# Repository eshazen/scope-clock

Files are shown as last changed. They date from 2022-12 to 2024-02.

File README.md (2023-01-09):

# Oscilloscope Clock

OK, time to jump on the oscilloscope clock bandwagon!
It's an old idea, but they just look so cool.

* [Wiki Page](http://hertz.bu.edu/~hazen/wiki/en/#!mdwiki/ScopeClock.md)

This was going to be a simple clone of some rather simplistic
transistor-based designs around the internet, but now I've got
something more ambitious in mind!  Here's the prototype in action:

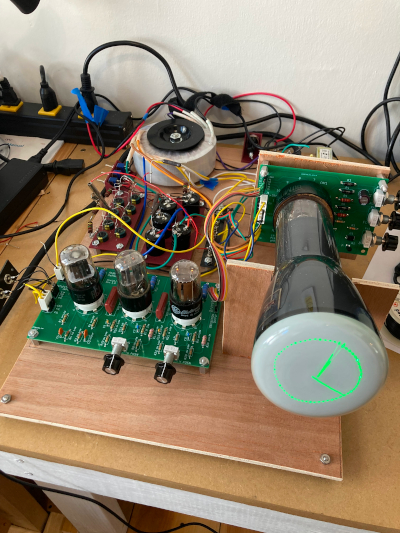
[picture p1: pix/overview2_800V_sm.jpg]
Prototype

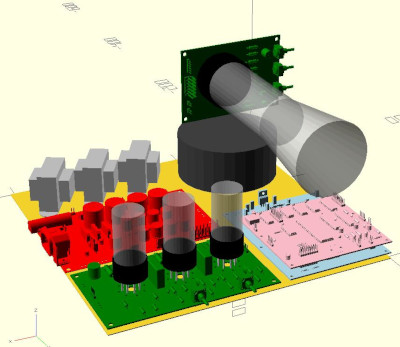
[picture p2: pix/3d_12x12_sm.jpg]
3D View


## Hardware

* 3BP1(A) CRT with proper drive to +360/-1400V [pcb](https://github.com/eshazen/scope-clock/tree/main/hardware/anderson_crt)
* Tube-based deflection circuit using 6SN7 or 12SN7 dual triodes [pcb](https://github.com/eshazen/scope-clock/tree/main/hardware/deflection_amp)
* Voltage-multiplier HV supply using an Antek transformer
* Display-list based vector graphics generator (or could cheat and use a uC)

## Attribution

The CRT circuit is directly inspired by Steve Anderson's narrow-bandwidth TV (NBTV) monitor design, as found at https://www.taswegian.com/NBTV/forum/index.php.

**Status**

**2021-01-14** - Rev A tag after DAC PCBs and parts ordered.

Now looking at the power supply.

**2022-12-28** - more or less working.  Hand-wired high voltage
supply.  CRT PCB and deflection amp working with only a couple of tiny
issues.

Open issues:

* Deflection amp gets quite non-linear at around 60% deflection (-1600V on CRT).  At -800V it's fine.  Low end of diff output leg is around 250V.  The range 250-320 works well.
* If you switch off all the supplies together the CRT arcs inside (oops!).  Need to shut down the -1500V first and wait many seconds, then turn off the others.  Really need to figure out some sort of shutdown circuit
* The input has to be driven by a laptop.

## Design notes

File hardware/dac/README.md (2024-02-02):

# DAC board

This is the control/interface board, designed to work with the Z80 CPU board from my retro-25 calculator project [git](https://github.com/eshazen/retro-25/tree/master/hardware/cpu/RevA).

**See bottom for ECOs**

Features:

* MAX503/530 DAC.  Needs 1 address bit and 8 bit data with strobe.
* UART with FT232 USB interface.  Thinking of IM6402 since it's dead simple.  Needs a 16X clock.
* Buttons, encoders, maybe a couple of LED drives
* Z-axis drive (9-12V to J2 on CRT board; could be +/-5V)
* Real-time clock e.g. DS1306

The CPU board interface is somewhat limited-- there are only two decoded nIORQ+Addr strobes and no access to nWR or nRD.  However, there is one address line and 5 latched outputs, which could be used for direction or additional address decoding.

## J1 (16 pins)

This connector was intended to drive an LED board.  It has the
unbuffered data buss, one address line and two strobes decoded with
nIORQ and address only.

| Notes | Pin | | Pin | Notes |
|---|-----|---|-----|---|
| +5V | 1 | | 2 | D0 (unbuffered) |
| +5V | 3 | | 4 | D1 |
| GND | 5 | | 6 | D2 |
| GND | 7 | | 8 | D3 |
| GND | 9 | | 10  | D4 |
| nLED2 (strobe)  | 11  | | 12  | D5 |
| nLED1 (strobe)  | 13  | | 14  | D6 |
| A0 (unbuffered) | 15  | | 16  | D7 |

## J3 (16 pins)

This connector was intended to scan a matrix keyboard.  It has 5
latched outputs and 7 buffered inputs with pull-ups to +5.  There is
no access to the read strobe, so data to be read should be latched
somehow.  Also, there is no GND on this connector.

| Notes | Pin | | Pin | Notes |
|---|-----|---|-----|---|
| N/A | 1 | | 2 | N/A |
| N/A | 3 | | 4 | Input D0 |
| Input  D4 | 5 | | 6 | Input D1 |
| Output Q4 | 7 | | 8 | Input D2 |
| Output Q3 | 9 | | 10  | Input D3 |
| Output Q2 | 11  | | 12  | Input D4 |
| Output Q1 | 13  | | 14  | Input D5 |
| Output Q0 | 15  | | 16  | Input D6 |

## I/O Mapping/Decoding

**CPU I/O decode**

    00 - KB/serial WR
	40 - nLED1 WR       (functions via U5)
	80 - KB/serial RD
	C0 - nLED2 WR       (access RTC when Q4 high)
	
Strobe nLED1 (address 0x40) accesses the DAC.  This is write-only (Q0
must be '1') with the channel selected by Q1.  Address A0 selects the
low 8 bits or upper 4 bits of the DAC data.  Strobe nLED2 accesses
either the UART or the switch/LED register selected by Q2.

### Output bits (address 0)

| Bit | Function | 0 | 1 |
|-----|---|---|---|
| Q0  | Bus direction | RD | WR |
| | LSB of U5 | even addr | odd addr |
| Q1  | A2 of U5 | | |
| Q2  | Z enable | Z enabled | Z disabled |
| Q3  | UART reset | | reset UART |
| Q4  | RTC CE | | enable RTC access |
| | | | |

### Input bits (address 80)

| Bit | Value | Function |
|-----|---|---|
| KD0 | 01 | Shaft encoder sw |
| KD1 | 02 | Shaft encoder A  |
| KD2 | 04 | Shaft encoder B  |
| KD3 | 08 | SW1 |
| KD4 | 10 | SW2 |
| KD5 | 20 | RTC SDO |
| KD6 | | |

### LS138 (U5)

Accessed at addresses 40/41

| Zero | Addr | Q1 | A0 | Q0 | Function |
|---|---|----|----|----|---|
| 0 | 40 | 0  | 0  | 0  | UART Data Rd |
| 1 | 40 | 0  | 0  | 1  | UART Data Wr |
| 0 | 41 | 0  | 1  | 0  | Uart Status Rd |
| 1 | 41 | 0  | 1  | 1  | `nEXP` expansion latch Wr |
| 2 | 40 | 1  | 0  | 0  | |
| 3 | 40 | 1  | 0  | 1  | `nDACY` H=idle, L=load DACs, reset DAC addr |
| 2 | 41 | 1  | 1  | 0  | |
| 3 | 41 | 1  | 1  | 1  | `nDACX` L->H write DAC data, increment DAC addr |

### U3 expansion

Access by writing to address 41 with port zero low bits set to '01'.

| Bit | Funct |
|-----|---|
| 0 | LED D1 |
| 1 | LED D2 |
| 2 | LED D3 |
| 3 | RTC SDI |
| 4 | HV Enable |
| 5 | |

Propse to buffer the data with a latched output used to set direction,
and enable on the 'or' of the two decoded strobes.  Additional latched
outputs would serve as a device select.

The DAC (MAX503 or MAX530) requires only a strobe (nWR) and one
address line (A0, A1 tied) to update 10 or 12 bits using two successive write operations.

Each DAC would be mapped to two addresses so once enabled it could be
written fast using two I/O writes per word.  A single additional write
would be required to switch between X and Y channels using a device
select bit.

The UART requires one status port, one latched control port and input and output data ports.

## Changed for Rev 2

* Transistor pinout (Q1) is wrong **fixed**
* Jumper pins 22, 23 of U8, U9 (+5V to DAC missing) **fixed**

### Modifications to make the DAC run faster

* Add a '161 and a '139 so that the address cycles through the 4 DAC bytes automatically:
   * Disconnect nCE and wire to nWR **fixed**
   * Disconnect nLDAC and wire to nDACY (also to '161 nRESET)
   * Disconnect nDACX and wire to '161 CP and '139 nEN **fixed**
   * Wire '161 Q1 to '139 A0. **fixed**
   * Ground '139 A1 **fixed** 
   * Wire 139 O0 to DAC_X nWR and nCE **fixed**
   * Wire 139 O1 to DAC_Y nWR and nCE **fixed**
   * Wire '161 Q0 to both DAC A0+A1  **fixed**
* cut trace to pins 8,9 of U8, U9 (DAC A0, A1) **fixed**
* (wire U8 pin 8 to U3 pin 10) nope.  That's A0/A1 taken care of above
* Ground 12, 14, 17 on DAC **fixed**
* DAC VDD missing **fixed**
* Swap nEXP and nDACX on U5 **fixed**

* Wire RTC SDI (pin 12) to LED3 **fixed**

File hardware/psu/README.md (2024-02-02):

# Power Supply

## Status

**2023-02-23** Mostly working.  Relay wiring incorrect (see ECOs).  Otherwise all outputs
verified working, at least with no load.

## Rev A ECOs

* C13 should be much bigger, maybe 4700uF
* Bridge footprints are wrong (holes way too small)
* Relay wiring is incorrect
* Can't use the S4 or S6 outputs of the CW multipler,
only S5, S7.  Maybe add an S3 tap?  In any case, fix J14 wiring.

## Requirements

* AC power entry, fuse, power switch
* +8V for logic (~1A) regulator on CPU board makes 5V for DAC (Antek 6.3V winding too wimpy)
* -5V for Z axis drive (low current).  Should be regulated
* 8-stage CW generator for -1500V
   * Jumpers to select output voltage
   * Discharge circuit for power-down
* Voltage doubler for +360V with two-stage R-C filter (200 ohm, 100uF or so)
* Switched AC out (2x?) for 12V filament transfomer plus spare

It seems I have a bunch of surplus 12V transformers in my office, so probably will use two of those
to generate the +8V and -5V with bridge rectifiers.

## ECOs for Rev 1

* Relay wiring wrong.  Cut traces to J1 pins 1,3.  Wire pin 1 to Relay pin 11 and pin 3 to relay pin 12.
  (leave gap in cut, ~180VAC)
* Add bleeder on 360V!  (ouch!)

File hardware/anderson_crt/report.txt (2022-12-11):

Info: Processing symbol 'N1:'.
Info: Processing symbol 'U1:Package_DIP:DIP-4_W7.62mm'.
Info: Processing symbol 'RV3:Potentiometer_THT:Potentiometer_Vishay_148-149_Single_Horizontal'.
Info: Processing symbol 'RV2:Potentiometer_THT:Potentiometer_Vishay_148-149_Single_Horizontal'.
Info: Processing symbol 'RV1:Potentiometer_THT:Potentiometer_Vishay_148-149_Single_Horizontal'.
Info: Processing symbol 'R8:Resistor_THT:R_Axial_DIN0207_L6.3mm_D2.5mm_P10.16mm_Horizontal'.
Info: Processing symbol 'R7:Resistor_THT:R_Axial_DIN0411_L9.9mm_D3.6mm_P12.70mm_Horizontal'.
Info: Processing symbol 'R6:Resistor_THT:R_Axial_DIN0411_L9.9mm_D3.6mm_P12.70mm_Horizontal'.
Info: Processing symbol 'R5:Resistor_THT:R_Axial_DIN0411_L9.9mm_D3.6mm_P15.24mm_Horizontal'.
Info: Processing symbol 'R4:Resistor_THT:R_Axial_DIN0411_L9.9mm_D3.6mm_P12.70mm_Horizontal'.
Info: Processing symbol 'R3:Resistor_THT:R_Axial_DIN0411_L9.9mm_D3.6mm_P12.70mm_Horizontal'.
Info: Processing symbol 'R2:Resistor_THT:R_Axial_DIN0309_L9.0mm_D3.2mm_P15.24mm_Horizontal'.
Info: Processing symbol 'R1:Resistor_THT:R_Axial_DIN0207_L6.3mm_D2.5mm_P10.16mm_Horizontal'.
Info: Processing symbol 'Q1:Package_TO_SOT_THT:TO-92_HandSolder'.
Info: Processing symbol 'C1:Capacitor_THT:CP_Radial_D10.0mm_P5.00mm'.
Info: Processing symbol 'J4:Connector_PinSocket_2.54mm:PinSocket_1x02_P2.54mm_Vertical'.
Info: Processing symbol 'J3:Connector_PinSocket_2.54mm:PinSocket_1x06_P2.54mm_Vertical'.
Info: Processing symbol 'J2:Connector_PinSocket_2.54mm:PinSocket_1x02_P2.54mm_Vertical'.
Info: Processing symbol 'J1:Connector_Molex:Molex_KK-396_5273-06A_1x06_P3.96mm_Vertical'.
Info: Processing symbol 'D3:Diode_THT:D_DO-35_SOD27_P10.16mm_Horizontal'.
Info: Processing symbol 'D2:Diode_THT:D_DO-35_SOD27_P7.62mm_Horizontal'.
Info: Processing symbol 'D1:Diode_THT:D_DO-35_SOD27_P10.16mm_Horizontal'.
Info: Processing symbol 'CRT1:CRT_base:B14_diheptal'.
Warning: No net found for symbol CRT1 pin 12.
Warning: No net found for symbol CRT1 pin 11.
Warning: No net found for symbol CRT1 pin 10.
Warning: No net found for symbol CRT1 pin 8.
Warning: No net found for symbol CRT1 pin 7.
Warning: No net found for symbol CRT1 pin 4.
Error: Cannot add N1 (no footprint assigned).

Info: Total warnings: 0, errors: 1.

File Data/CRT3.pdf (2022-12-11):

PWM Grid-Drive Applied to a CRT display.

Preamble.

One of the factors to consider when using a CRT as a display device is its inherent Gamma whereby the light output on the tube-face is not a linear function of the grid voltage. It’s basically a squaring function, vg

2
, which is expressed as a Gamma of 2. Luckily early vacuum-state camera tubes such as Vidicons and the like had a complimentary Gamma of 0.5, a square-root function. The numbers are approximate, 2.2 and 0.45 were often used in practice.

Today virtually all photo-sensitive devices are linear, e.g. photo-diodes, photo-transistors and CCDs unless used in the photo-voltaic mode where it becomes a natural logarithmic function, ln. If using a linear light output device such as an LED in current drive all is well, linear to linear. But if using a mixture you need to Gamma-encode a linear photo-sensor or ‘un-Gamma’ a CRT.

There are a number of ways to do this in the analogue world but here we ‘un-Gamma’ the CRT in a different manner. Simply the CRT is on or off. A high-frequency square-wave is applied to the grid and this is pulse width modulated to achieve a linear output for a linear input. Only two points on the grid curve are used, cut-off or at a single current point. The curve itself now becomes irrelevant.

Here is this method as applied to a non-standard NBTV picture monitor, but it can be applied to virtually Any CRT picture or information display. In a colour CRT it would need to be the three separate cathodes that would need to be driven instead of the grid circuit, but the principle is the same.

An outline of the differences between this system and the more conventional mechanical display is in order, this is interim; and will be developed in time to cater for more lines and a higher frame rate:-

1). Scanning is left-to-right for the lines and top-to-bottom for the frame, the same as 525/625 TV. 2). The aspect ratio is 4:3, slightly landscape, again the same as conventional TV.
3). There are 48 lines each consisting of 64 pixels, the line rate is 600Hz and frame rate is 12.5Hz. 4). This is a sync-less system with (currently) the exception of a frame reference.
5). There is black-level clamping ensuring true luminance values.
Caution.

This unit uses both high AC and DC voltages and the author of this in no way accepts any responsibility for any incident, injury or fatality of those attempting to replicate it. If you’re not used to working with high voltages, get some experienced supervision. Although this is considered a low-voltage CRT, there is nigh on 1000V of potential difference in parts of the device. Do not work on this alone.
Basic Signal Characteristics.

The source material is from a .wav file played back on a PC; this is sampled at 48kHz with eight-bit video resolution. At a line rate of 600Hz this yields 80 pixels per line of which only 64 contain active video, the other 16 at the end of each line are set to black level. This was originally for black-level clamping but it proved unnecessary, more on this later.

There are no sync pulses used with the exception of a ‘frame reference’ consisting of 16 cycles of full amplitude 24kHz at the start of line 48. This is followed by a black reference for the remainder of the line where the black-level clamping is done once per frame. Sadly we lose one line in 48, but I plan to recover line 48.

The snapshot to the left shows the input waveform from the PC (yellow) with the video utilizing the entire 8-bit resolution and the 24kHz burst for line 48 identification followed by the black reference.

The cyan trace is the 24kHz bandpass filter output (IC204b pin 7, Fig. 1 below). The magenta trace is the envelope detector output (C210) and the green trace is the comparator output (IC205 pin 7).

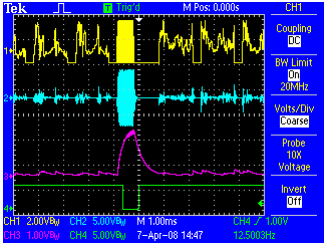
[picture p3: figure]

This all relies on the exactitude of two oscillators, one in the PC which drives the audio D-A and the one in the display. The oscillator in my PC is around 32ppm off-frequency, whereas the displays reference is far more accurate.

This results in a slow drift in line-rates, around one line in 90 seconds. But with a refresh every frame results in an error of around one tenth of a pixel per frame. I did consider adding a 24kHz reference signal to the right audio channel which would have made things very easy, but I felt this would be cheating.
The circuits.

Figure 1 shows the input side of things where the signal from the PC is increased to 7V p/p and followed by a band-pass filter to extract the frame 24kHz burst. Flat-out my PC outputs 3.5V p/p, adjust R216 to suit other levels. IC204b is the band-pass filter that detects the 24kHz burst followed by a simple detector comprising D201 and associated components. See waveform above.

(Continued on next page).

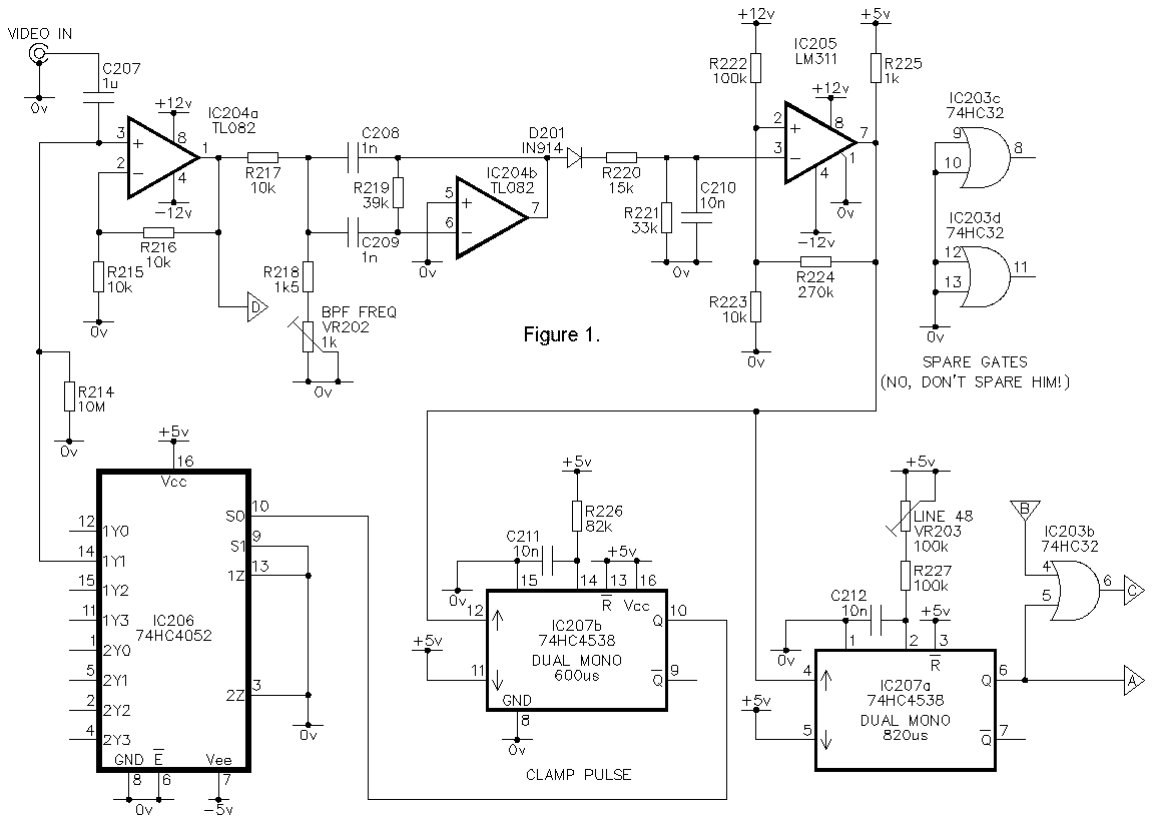
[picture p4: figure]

This is then cleaned up by IC205, a comparator which generates a pulse that triggers IC207a and IC207b. IC 207b is the black-level clamping monostable that enables IC206 welding the black reference to zero volts that follows the burst in line 48. I did try a LM/NE567 tone decoder, but with only 16 cycles to work with it was susceptible to false triggering from the actual video waveform.

Once the 24kHz frame sync is detected IC201b is continually retriggered to illuminate a green LED which indicates the presence of a NBTV signal with frame reference.

(Continued on next page).

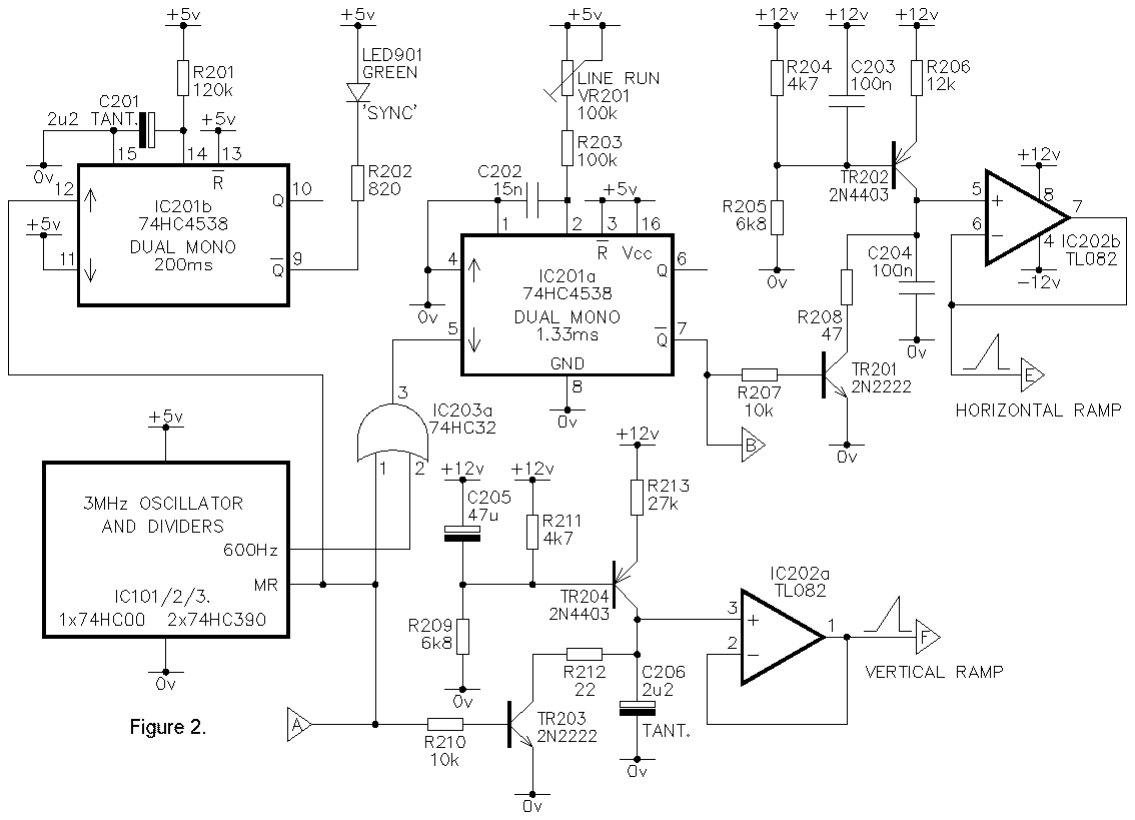
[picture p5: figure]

Due to the slight difference in clock frequencies all the counters in the division from 3MHz that generate the timing of the timebase waveforms, both horizontally and vertically, are reset at each detection of frame sync (Fig. 2). IC207a generates a pulse to add the missing line one sync when the counters are reset to zero. IC203b is a ‘leftover’ from previous versions of this, it’s not needed. Pin 5 could be at ground or IC203b could be omitted entirely.

IC201a in conjunction with TR201 and TR202 generate the horizontal deflection waveform at 600Hz. In a similar manner TR203 and TR204 generate the vertical ramp waveform.

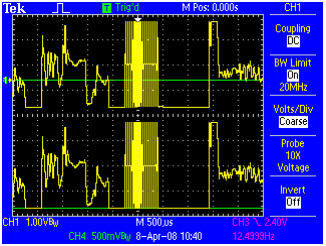
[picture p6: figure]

Black level clamping is performed by IC206 (Fig. 1) driven by the clamp pulse from IC207b. The waveforms to the left show the normal AC-coupled output of the PC at the top, the green trace indicating ground/0V. The lower one shows the black being clamped to ground.

The deflection circuits that feed the CRT plates are conventional differential stages, TR301 to TR306 (Fig. 3). C301 and C305 were not necessary in this slow speed application.

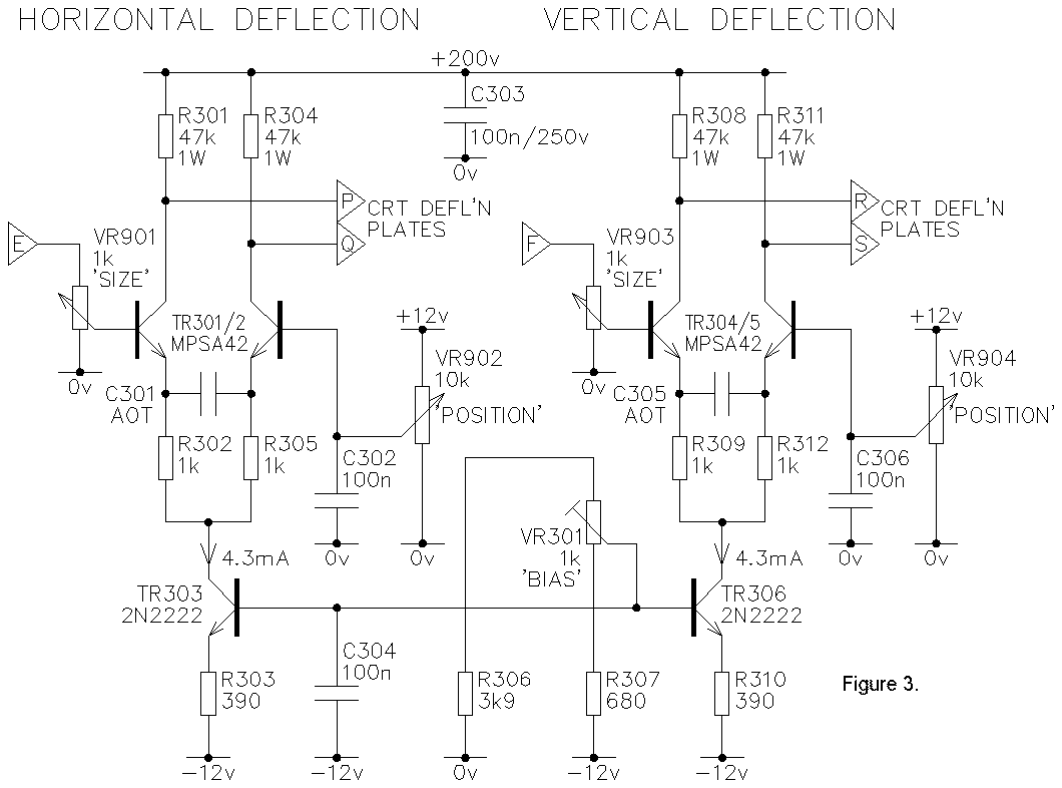
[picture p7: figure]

Fig. 4 shows how the PWM
of the grid is done via a fast logic opto-coupler to isolate the nasty voltages around
the grid and cathode
potentials of the CRT. TP1 and R417 were added to
observe the PWM
waveform at the grid
without the scope probes
capacitance slowing things down. TR402/3 stop the
PWM oscillator during
blanking/retrace time which makes it synchronous and
shuts off the drive to the IR LED.

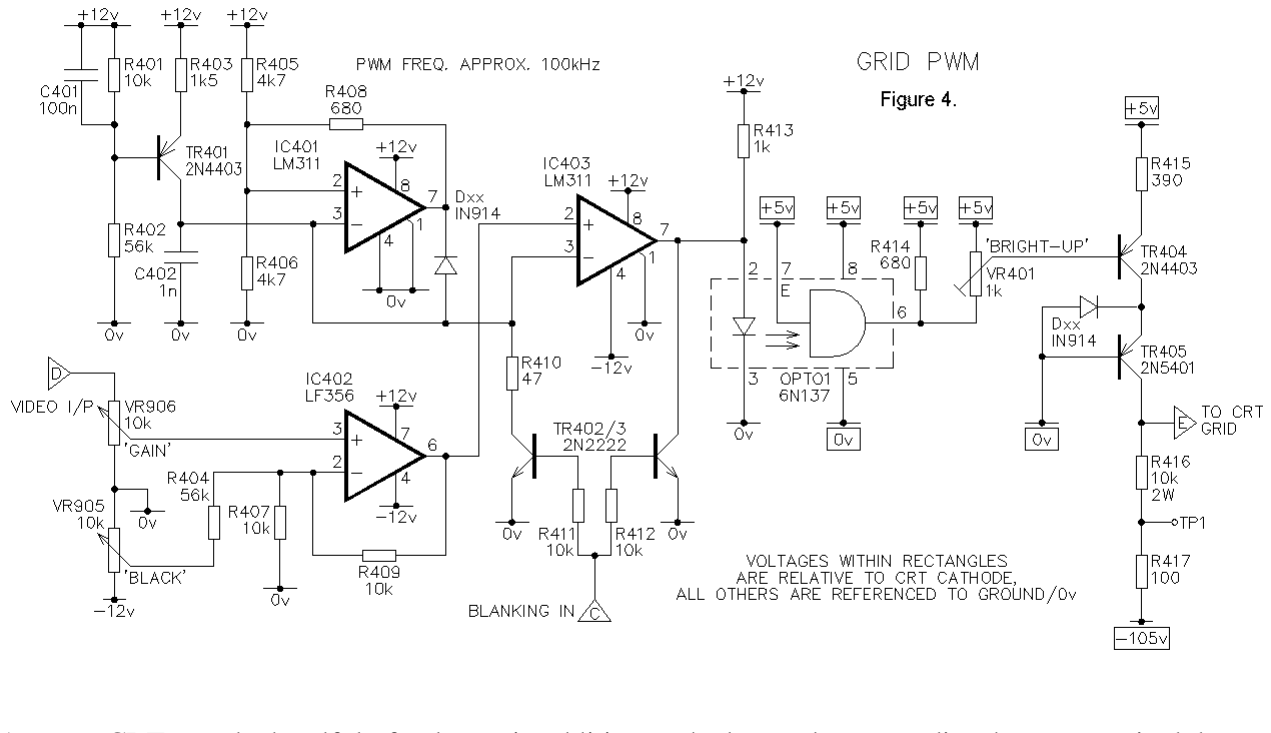
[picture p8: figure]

As ever, CRTs need a handful of voltages in addition to the low-voltage supplies that are required, hence the complexity of the PSU and CRT circuit that follows (Fig. 5). This was not helped by the unavailability of suitable transformers, hence the use of back-to-back transformers and the requirement of voltage multiplication. The transformers used have some strange voltages, but I had them to hand. R909 and R910 were added to the CRT heater circuit to reduce the inrush current when first switched on cold.

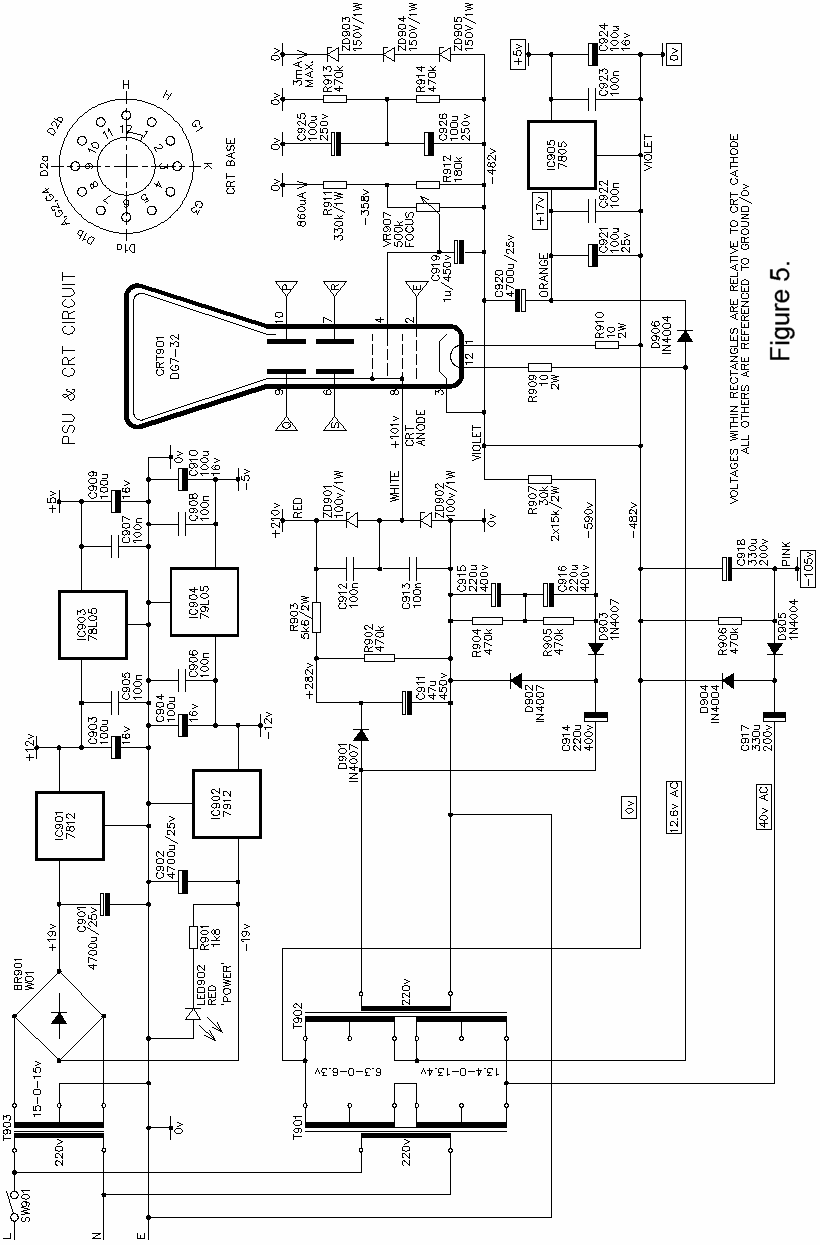
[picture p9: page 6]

The Results.

So, after all that effort what’s the upshot of it all? Pictures are worth a thousand words…

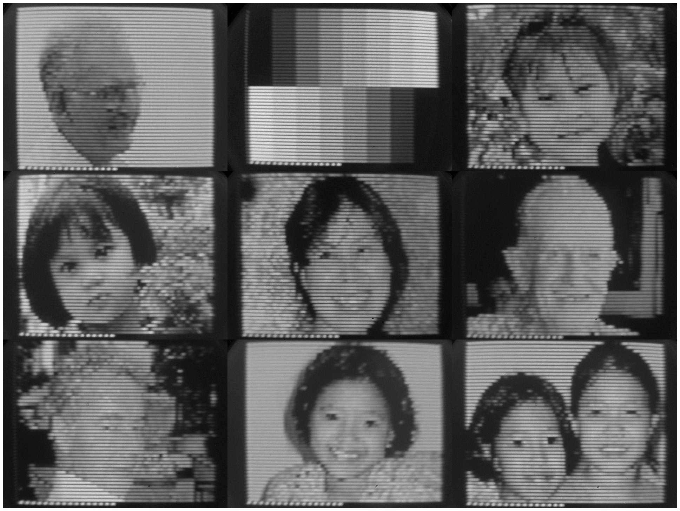
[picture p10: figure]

You can see the vertical burst in the first half of the last line. I deliberately didn’t blank it as I wish to be able to see the visible effects as I modify it.
Further Developments.

Using a 7cm (3”) tube with a nominal line-width of 0.5mm this is about the limit of resolution for a DG7-32, next it’s going to be a 13cm (5”) 5ADP1 with an increase in the number of lines to 60/80/96, and a minor increase in voltage to 3000V. Another advantage of the 5ADP1 is that it has a flat faceplate so the curvature distortion introduced by the DG7-32 should be reduced or eliminated.

However, seeing as the 3” display was already in operation it was a simple task to change it to being a 72-line display. This was done by reducing the frame rate to 6.67Hz, the flicker of course was greater than at 12.5Hz. Only one resistor needed changing, R213 was increased to 47k, VR201 and VR203 having enough adjustment range…but only just! The frequency dividers were altered to provide a line rate of 480Hz as opposed to 600Hz. Some sample screen-shots follow…

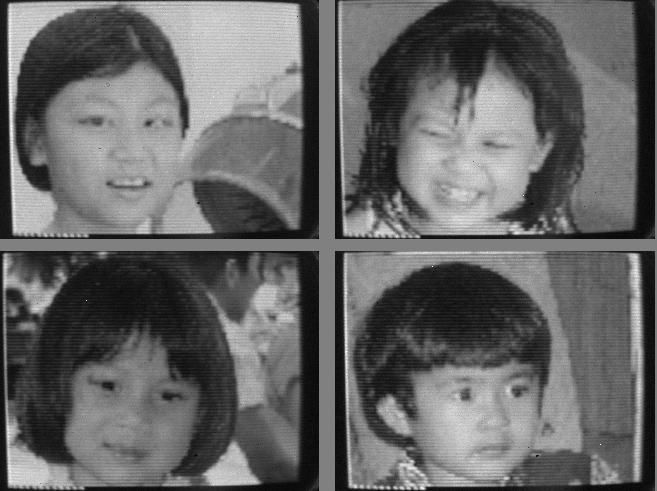
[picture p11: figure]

This display and the methods used were mainly a ‘proof of concept’ exercise; the display will again be torn down and used for something else.

If anyone should have any comments or questions please contact me at the e-mail address below.

Steve Anderson. © Steve Anderson 2008. steveand@truemail.co.th

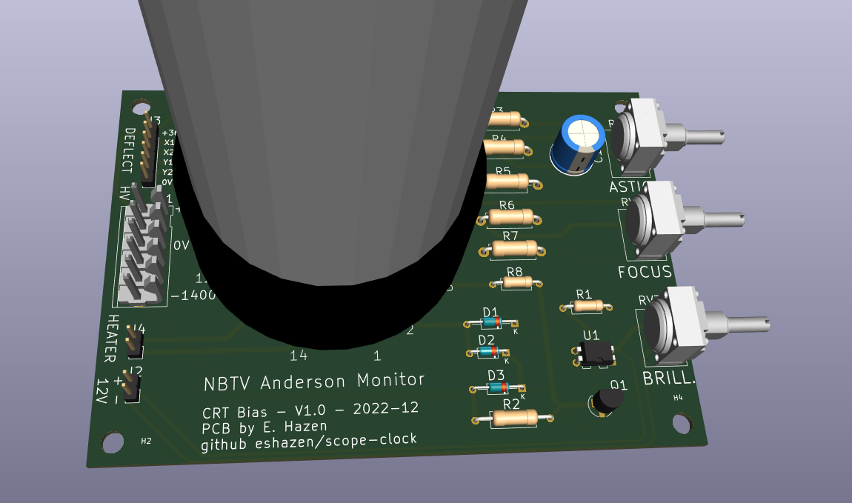
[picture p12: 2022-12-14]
hardware/anderson_crt/anderson_crt.pcb_3D.png

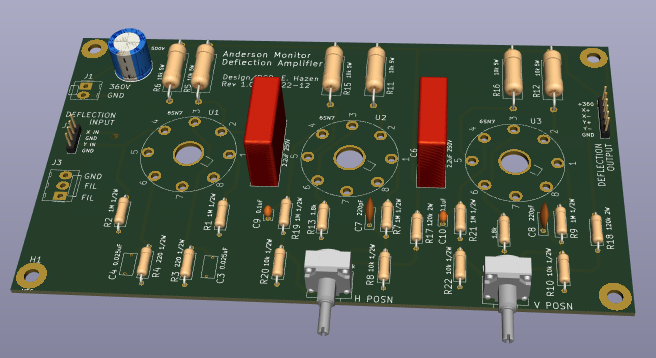
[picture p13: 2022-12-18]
hardware/deflection_amp/deflection_amp_pcb_3D.png

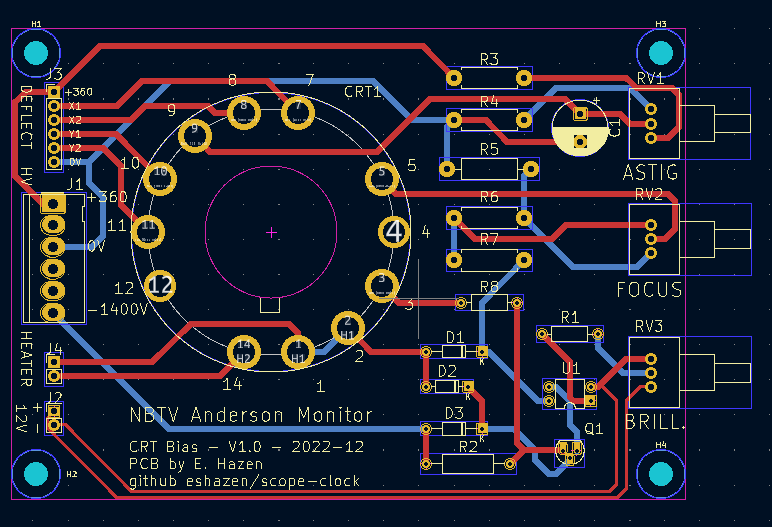
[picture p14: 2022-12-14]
hardware/anderson_crt/anderson_crt.pcb_layout.png

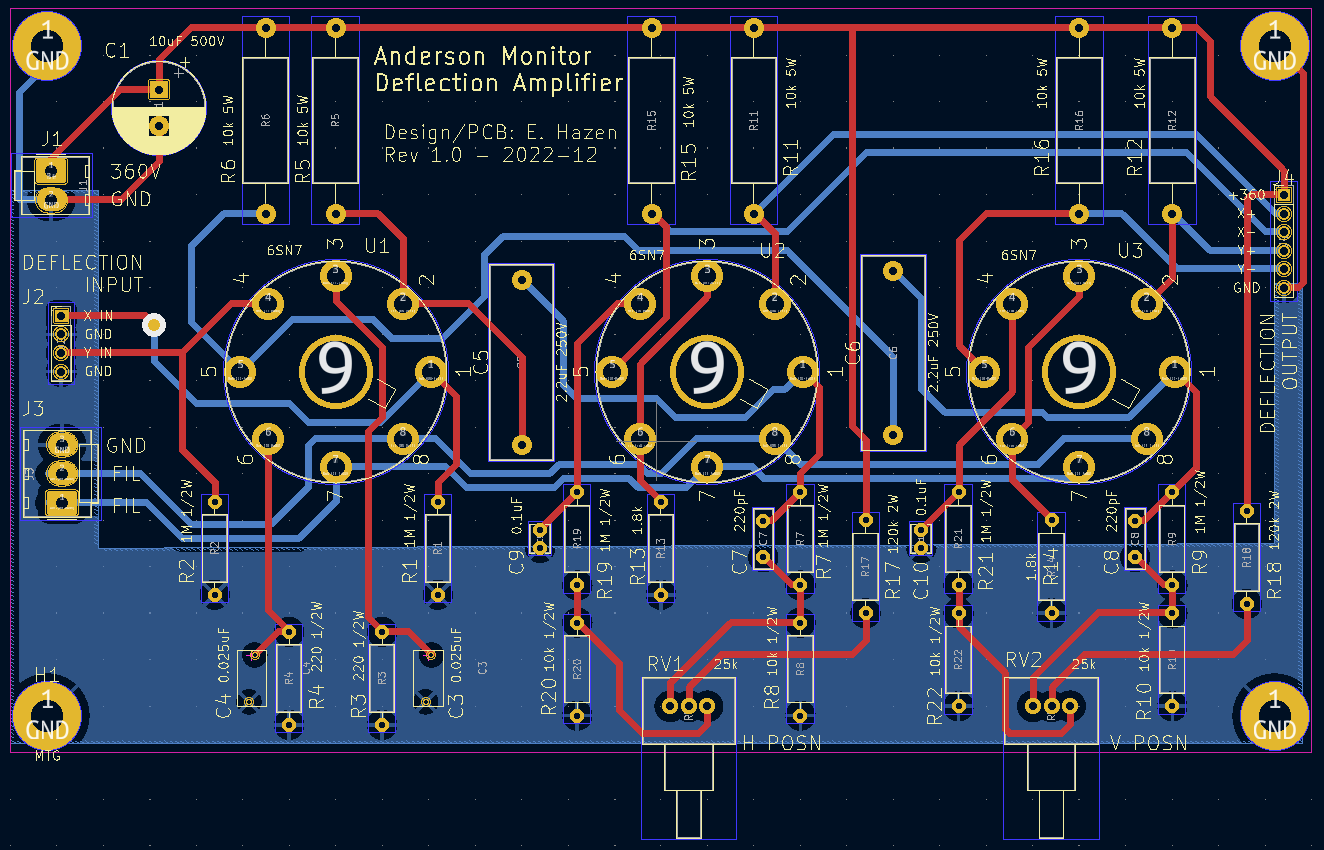
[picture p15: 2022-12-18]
hardware/deflection_amp/deflection_amp_pcb.png

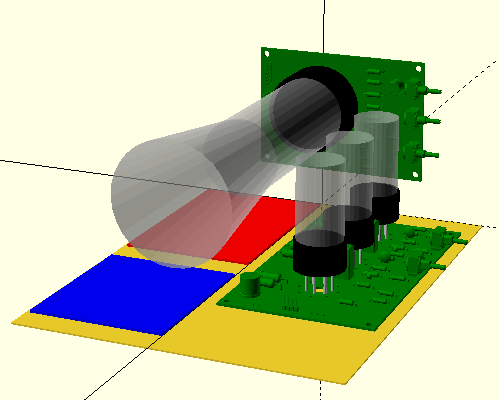
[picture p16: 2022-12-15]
pix/3d_pre.jpg

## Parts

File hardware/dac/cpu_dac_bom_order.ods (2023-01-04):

Reference | Quantity | Value | Footprint | CatNo
C1 | 1 | 10uF |  | 718-1212-ND
C2 | 1 | 0.33uF |  | 478-3188-ND
C3 C4 C5 C6 C7 C8 C9 C10 C11 C12 C13 C14 C15 C16 C17 C18 C19 | 17 | 0.1uF |  | 478-3188-ND
D1 D3 | 2 | LED
D2 | 1 | 1N914
D4 D5 | 2 | 1N914 | Diode_THT:D_DO-35_SOD27_P7.62mm_Horizontal
J1 J3 | 2 | hdr_2x8
J2 | 1 | Conn_01x06
J5 | 1 | Conn_01x02 |  | A31676-ND
JP1 | 1 | jpr3
R1 R5 | 2 | 470
R2 R7 | 2 | 4.7k
R3 | 1 | 1k
R4 | 1 | 10k
RN1 | 1 | RPACK_SIP_8 | Resistor_THT:R_Array_SIP9 | 4609X-AP1-103LFCT-ND
SW1 | 1 | SW_Push |  | 401-1985-ND
U1 U17 | 2 | 74AS74 |  | 296-1525-5-ND
U13 | 1 | 74LS32 |  | 296-1658-5-ND
U16 | 1 | uA7805 |  | MC7805CT-BPMS-ND
U2 | 1 | 74LS374 |  |  | Get from BU
U3 | 1 | Z80CPU |  |  | Have 2 6MHz
U4 | 1 | AT28C256-15PU | Package_DIP:DIP-28_W15.24mm | AT28C256-15PU-ND | Jameco
U5 | 1 | 74LS244 |  | 296-1653-5-ND
U6 | 1 | 74HC14 |  | 296-1577-5-ND
U7 | 1 | 74LS139 |  | 296-1640-5-ND
U8 | 1 | AS6C62256-55PCN | Package_DIP:DIP-28_W15.24mm | 1450-1033-ND
X1 | 1 | 20.000MHz | Oscillator:Oscillator_DIP-14 |  | Have 8MHZ
BT1 | 1 | Battery_Cell | Connector_PinHeader_2.54mm:PinHeader_1x02_P2.54mm_Vertical
C1 C2 C3 C4 C5 C6 C7 C8 C9 C10 C11 C12 C13 C16 | 14 | 0.1uF | Capacitor_THT:C_Disc_D3.4mm_W2.1mm_P2.50mm | 399-9859-1-ND
C14 C15 | 2 | 33uF | Capacitor_THT:CP_Radial_D5.0mm_P2.00mm | 732-9408-1-ND
C17 C18 | 2 | 3.3uF 10V | Capacitor_THT:CP_Radial_D5.0mm_P2.50mm
D1 D2 D3 | 3 | LED | LED_THT:LED_D3.0mm | 1497-XLMDK65D-ND
H1 H2 H3 H4 | 4 | MountingHole | MountingHole:MountingHole_3.2mm_M3
IC1 | 1 | EC1110120201_with_knurled_SHAFT | ShaftEnc:EC1110120201withknurledSHAFT | 688-EC1110120201KS
J1 J7 | 2 | Conn_01x04 | Connector_PinHeader_2.54mm:PinHeader_1x04_P2.54mm_Vertical
J2 J3 J4 | 3 | Conn_02x08_Odd_Even | Connector_PinHeader_2.54mm:PinHeader_2x08_P2.54mm_Vertical
J5 | 1 | Conn_01x02 | Connector_PinHeader_2.54mm:PinHeader_1x02_P2.54mm_Vertical
J6 | 1 | Conn_01x04 | Connector_PinHeader_2.54mm:PinHeader_1x04_P2.54mm_Horizontal
Q1 | 1 | Q_PNP_BCE | Package_TO_SOT_THT:TO-92 | 2N3906FS-ND
R1 R2 R3 | 3 | R_US | Resistor_THT:R_Axial_DIN0207_L6.3mm_D2.5mm_P10.16mm_Horizontal
R4 R7 | 2 | 10k | Resistor_THT:R_Axial_DIN0207_L6.3mm_D2.5mm_P10.16mm_Horizontal
R5 R6 | 2 | 1k | Resistor_THT:R_Axial_DIN0207_L6.3mm_D2.5mm_P10.16mm_Horizontal
SW1 SW2 | 2 | SW_SPST | Connector_PinHeader_2.54mm:PinHeader_1x02_P2.54mm_Vertical
U1 | 1 | 74HC4040 | Package_DIP:DIP-16_W7.62mm | 296-8324-5-ND
U2 | 1 | 74LS08 | Package_DIP:DIP-14_W7.62mm | 296-1633-5-ND
U3 | 1 | 74LS174 | Package_DIP:DIP-16_W7.62mm | 296-3664-5-ND
U4 | 1 | 74HCT245 | Package_DIP:DIP-20_W7.62mm | 296-1612-5-ND
U5 | 1 | 74LS138 | Package_DIP:DIP-16_W7.62mm | 296-1639-5-ND
U6 | 1 | DS1306 | Package_DIP:DIP-16_W7.62mm | DS1306+-ND
U7 | 1 | IM6402 | Package_DIP:DIP-40_W15.24mm | 2156-HD3-6402C-9-ND
U8 U9 | 2 | MAX503 | Package_DIP:DIP-24_W7.62mm | MAX503CNG+-ND
X1 | 1 | 4.9152MHz | Oscillator:Oscillator_DIP-8 | XC260-ND
Y1 | 1 | 32.768 kHz | Crystal:Crystal_C26-LF_D2.1mm_L6.5mm_Horizontal | 300-8761-ND
SKT-40 | 2 | 40 pin socket
SKT-28 | 2 | 28 pin socket
SKT-20 | 3 | 20 pin socket
SKT-14 | 5 | 14 pin socket
SKT-16 | 8 | 16 pin socket
Stack-Con | 2 | 16 pin stacker header |  | 612-ZW-08-09-F-D-440-110-ND
Stack-Skt | 2 | 16 pin stack socket |  | S9196-ND
SKT-24 | 2 | 24 pin 0.300 socket

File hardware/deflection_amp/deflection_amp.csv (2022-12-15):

Reference | Quantity | Value | Footprint | Datasheet | CatNo
C1 | 1 | 10uF 500V | Capacitor_THT:CP_Radial_D12.5mm_P5.00mm |  | 493-6892-ND
C3 C4 | 2 | 0.025uF | HV_Ceramic_Cap:Cap-Disc-D7.4-P6.4 |  | 561R10TCCQ25-ND
C5 C6 | 2 | 2.2uF 250V | Capacitor_THT:C_Rect_L26.5mm_W8.5mm_P22.50mm_MKS4 |  | EF2225-ND
C7 C8 | 2 | 220pF | Capacitor_THT:C_Disc_D8.0mm_W2.5mm_P5.00mm |  | 445-173352-1-ND
C9 C10 | 2 | 0.1uF | Capacitor_THT:C_Disc_D3.8mm_W2.6mm_P2.50mm |  | 399-14010-2-ND
H1 H2 H3 H4 | 4 | MTG | MountingHole:MountingHole_4.5mm_Pad
J1 | 1 | Conn_01x02 | Connector_Molex:Molex_KK-396_A-41791-0002_1x02_P3.96mm_Vertical |  | WM2122-ND
J2 | 1 | Conn_01x04 | Connector_PinHeader_2.54mm:PinHeader_1x04_P2.54mm_Vertical
J3 | 1 | Conn_01x03 | Connector_Molex:Molex_KK-396_A-41791-0003_1x03_P3.96mm_Vertical |  | WM50010-03-ND
J4 | 1 | Conn_01x06 | Connector_PinHeader_2.54mm:PinHeader_1x06_P2.54mm_Vertical
R1 R2 R7 R9 R19 R21 | 6 | 1M 1/2W | Resistor_THT:R_Axial_DIN0309_L9.0mm_D3.2mm_P12.70mm_Horizontal |  | CF12JT1M00TR-ND
R13 R14 | 2 | 1.8k | Resistor_THT:R_Axial_DIN0309_L9.0mm_D3.2mm_P12.70mm_Horizontal |  | S1.8KHTR-ND
R17 R18 | 2 | 120k 2W | Resistor_THT:R_Axial_DIN0309_L9.0mm_D3.2mm_P12.70mm_Horizontal |  | 120KZTR-ND
R3 R4 | 2 | 220 1/2W | Resistor_THT:R_Axial_DIN0309_L9.0mm_D3.2mm_P12.70mm_Horizontal |  | S220HTR-ND
R5 R6 R11 R12 R15 R16 | 6 | 10k 5W | Resistor_THT:R_Axial_DIN0617_L17.0mm_D6.0mm_P25.40mm_Horizontal |  | A142824CT-ND
R8 R10 R20 R22 | 4 | 10k 1/2W | Resistor_THT:R_Axial_DIN0309_L9.0mm_D3.2mm_P12.70mm_Horizontal |  | S10KHTR-ND
RV1 RV2 | 2 | 25k | Vishay_Pot_148:Potentiometer_Vishay_148-149_Single_Horizontal |  | 693-14910F0GJSX10253KA-ND
U1 U2 U3 | 3 | 6SN7 | Octal_Sockets:AES-P-ST8-193 | http://www.r-type.org/pdfs/ecc81.pdf | AES P-ST8-193

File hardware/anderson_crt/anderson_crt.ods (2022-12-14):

Reference | Quantity | Value | Footprint | Datasheet | CatNo
C1 | 1 | 10uF 400V | Capacitor_THT:CP_Radial_D10.0mm_P5.00mm |  | 493-13313-1-ND
CRT1 | 1 | 3BP1(A) | CRT_base:B14_diheptal
D1 | 1 | 5.1V 400mW | Diode_THT:D_DO-35_SOD27_P10.16mm_Horizontal |  | 1727-2111-1-ND
D2 | 1 | 1N914 | Diode_THT:D_DO-35_SOD27_P7.62mm_Horizontal | http://www.vishay.com/docs/85622/1n914.pdf | 1N914FS-ND
D3 | 1 | 75v 400mW | Diode_THT:D_DO-35_SOD27_P10.16mm_Horizontal |  | 1727-6138-1-ND
H1 H2 H3 H4 | 4 | MountingHole | MountingHole:MountingHole_4.3mm_M4
J1 | 1 | Conn_01x06 | Connector_Molex:Molex_KK-396_5273-06A_1x06_P3.96mm_Vertical |  | WM50010-06-ND
J2 J4 | 2 | Conn_01x02 | Connector_PinHeader_2.54mm:PinHeader_1x02_P2.54mm_Vertical
J3 | 1 | Conn_01x06 | Connector_PinHeader_2.54mm:PinHeader_1x06_P2.54mm_Vertical
N1 | 12 | socket_pins |  |  | ED5034-ND
Q1 | 1 | KSA1013YTA | Package_TO_SOT_THT:TO-92_HandSolder |  | KSA1013YTACT-ND
R2 | 1 | 47k | Resistor_THT:R_Axial_DIN0309_L9.0mm_D3.2mm_P15.24mm_Horizontal |  | CF12JT47K0CT-ND
R3 R4 R6 | 3 | 68k 1/2W | Resistor_THT:R_Axial_DIN0411_L9.9mm_D3.6mm_P12.70mm_Horizontal |  | A129363-ND
R5 | 1 | 470k 2W | Resistor_THT:R_Axial_DIN0411_L9.9mm_D3.6mm_P15.24mm_Horizontal |  | PPC470KW-2CT-ND
R7 | 1 | 220k 2W | Resistor_THT:R_Axial_DIN0411_L9.9mm_D3.6mm_P12.70mm_Horizontal |  | PPC220KW-2CT-ND
R8 | 1 | 1k | Resistor_THT:R_Axial_DIN0207_L6.3mm_D2.5mm_P10.16mm_Horizontal |  | 1.0KQBK-ND
RV1 | 1 | 100k | Vishay_Pot_148:Potentiometer_Vishay_148-149_Single_Horizontal |  | 693-14910F0GJSX10104KA-ND
RV2 | 1 | 1M | Vishay_Pot_148:Potentiometer_Vishay_148-149_Single_Horizontal |  | 693-14910F0GJSX10105KA-ND
RV3 | 1 | 5k | Vishay_Pot_148:Potentiometer_Vishay_148-149_Single_Horizontal |  | 693-14910F0GJSX10502KA-ND
U1 | 1 | PS2561 | Package_DIP:DIP-4_W7.62mm | http://www.vishay.com/docs/83740/sfh617a.pdf | 559-1318-ND

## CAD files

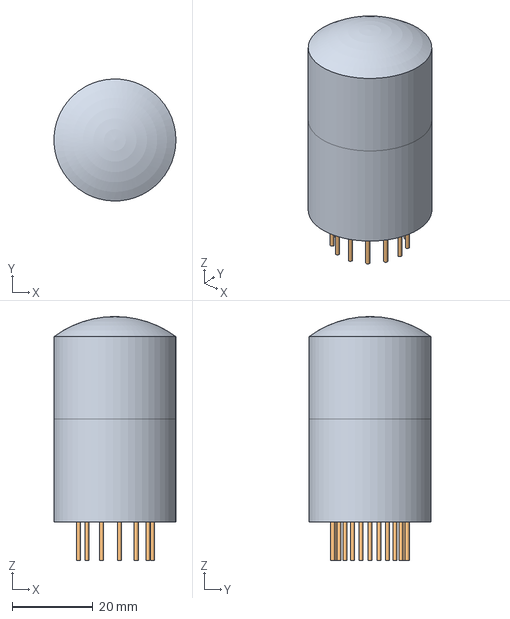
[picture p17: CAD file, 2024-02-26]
hardware/b_250_test/3D/6T9.step
30.1 x 30.2 x 60.3 mm

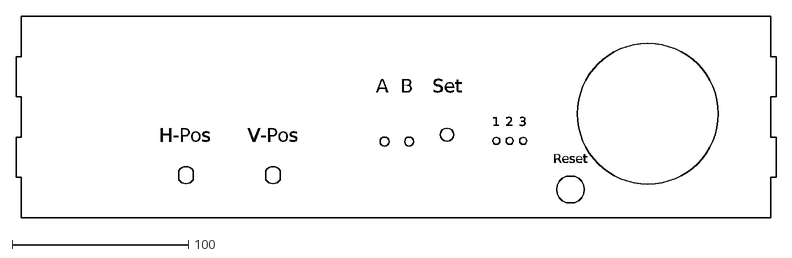
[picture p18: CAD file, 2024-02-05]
hardware/case/front2.dxf
H-Pos
V-Pos
Set
A
B
1
2
3
Reset

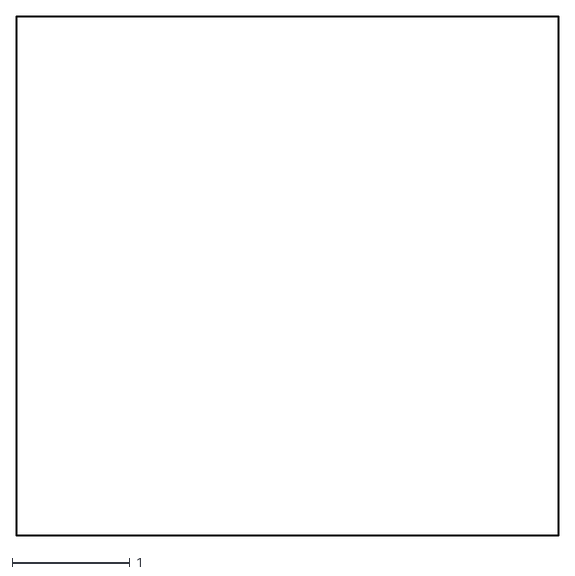
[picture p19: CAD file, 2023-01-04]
hardware/dac/dxf/dac-Edge_Cuts.dxf
4.60 x 4.40

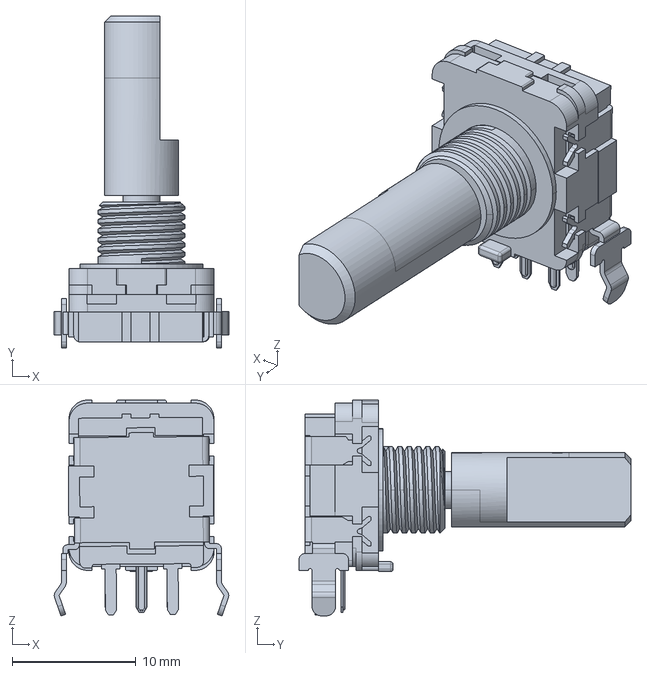
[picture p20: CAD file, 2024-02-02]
hardware/dac/models/EN11-VSM.STP
14.1 x 26.8 x 17.4 mm

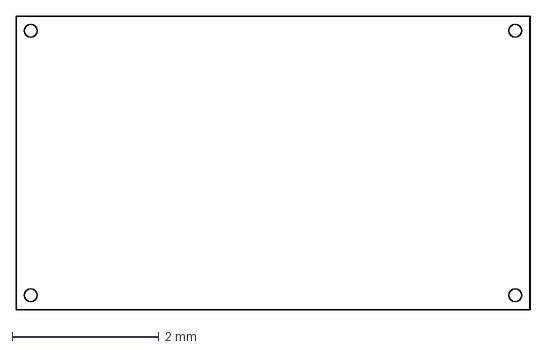
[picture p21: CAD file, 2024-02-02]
hardware/deflection_amp/3D/deflection_amp-mech.dxf
7.00 x 4.00 mm

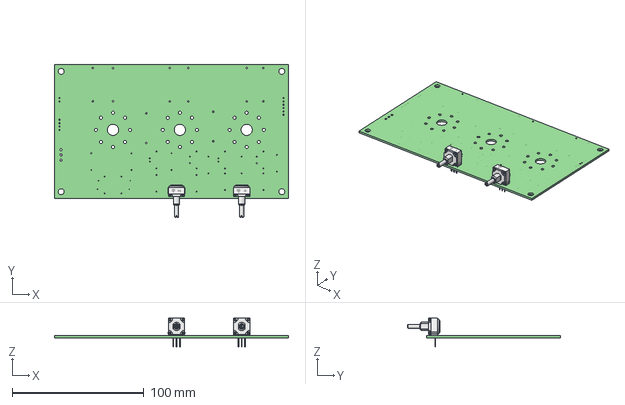
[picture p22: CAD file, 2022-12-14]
hardware/deflection_amp/deflection_amp.step
177.8 x 116.0 x 21.8 mm
deflection_amp PCB

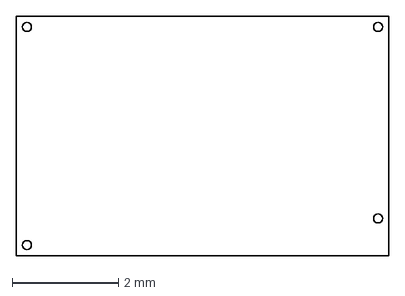
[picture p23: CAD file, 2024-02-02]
hardware/psu/3D/psu-mech.dxf
7.00 x 4.50 mm

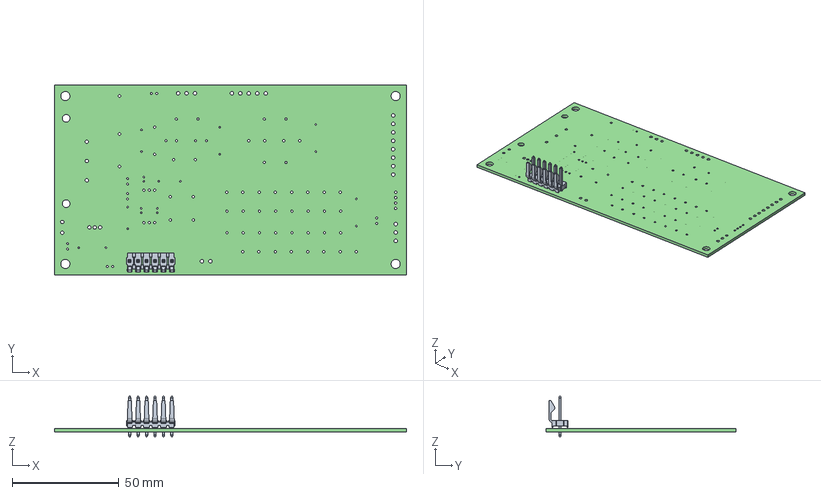
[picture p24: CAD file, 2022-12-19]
hardware/psu/psu.step
165.1 x 88.9 x 19.1 mm
psu PCB

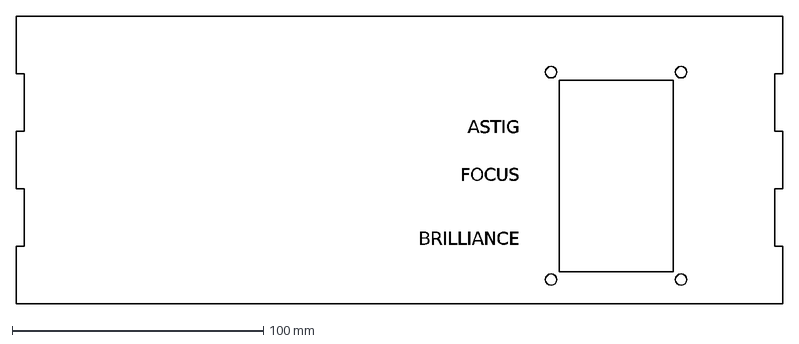
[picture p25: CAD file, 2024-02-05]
hardware/case/right.dxf
ASTIG
FOCUS
BRILLIANCE

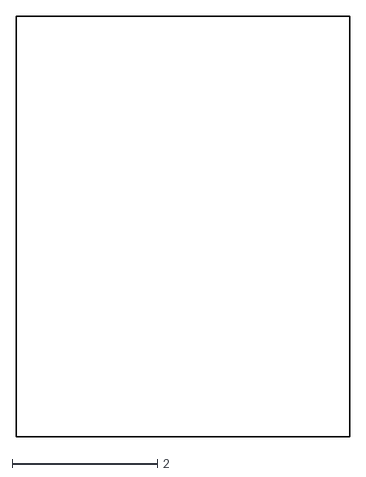
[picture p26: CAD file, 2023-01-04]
hardware/dac/dxf/cpu-Edge_Cuts.dxf
4.60 x 5.80

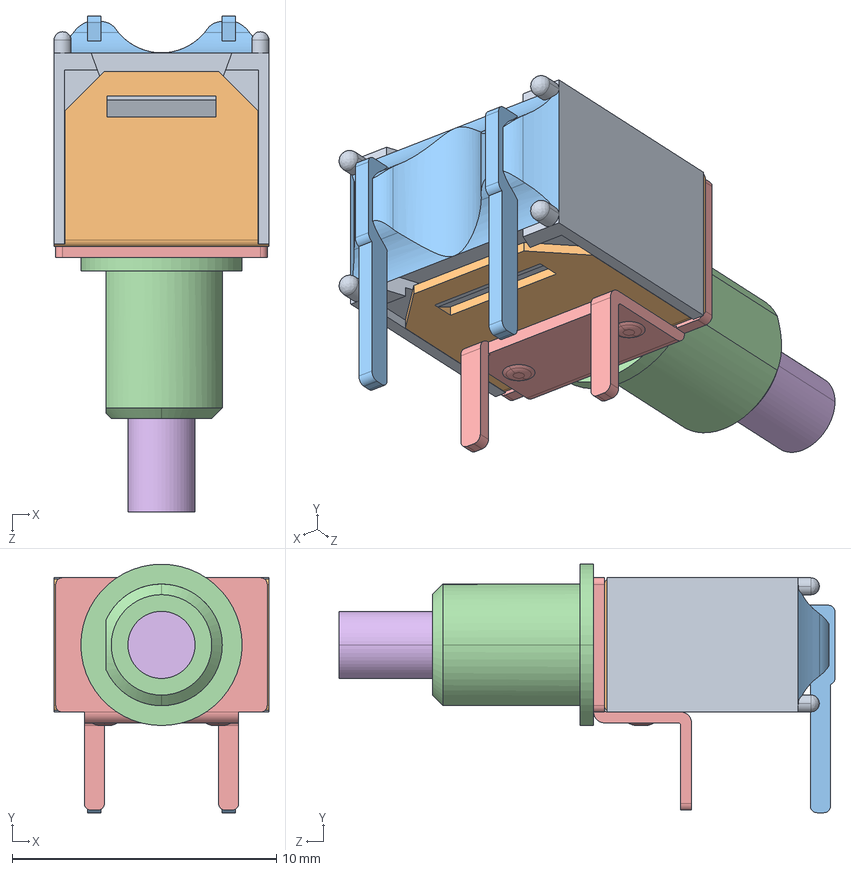
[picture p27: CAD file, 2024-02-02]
hardware/dac/models/800SP9B6M6RE.step
8.13 x 9.40 x 18.8 mm

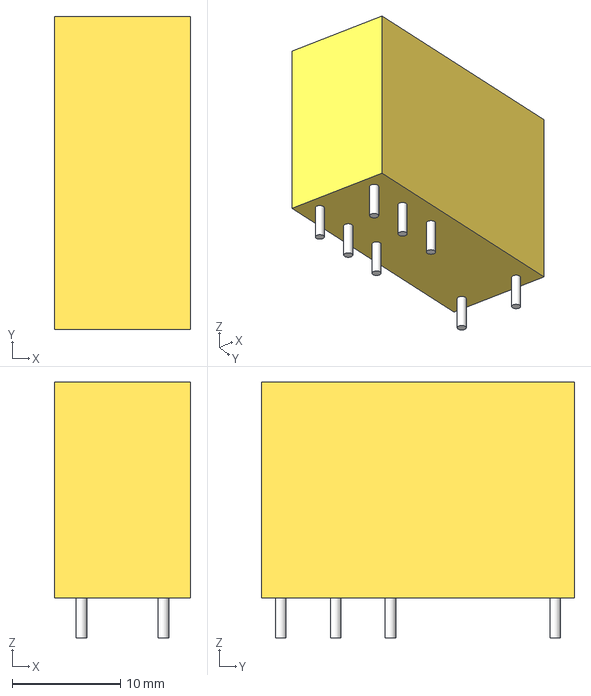
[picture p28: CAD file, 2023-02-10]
hardware/psu/3D/relay-Group003.step
12.6 x 29.0 x 23.7 mm

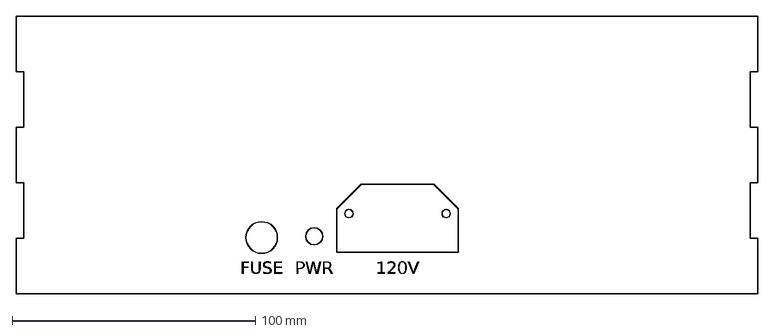
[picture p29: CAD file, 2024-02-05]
hardware/case/left.dxf
FUSE
PWR
120V

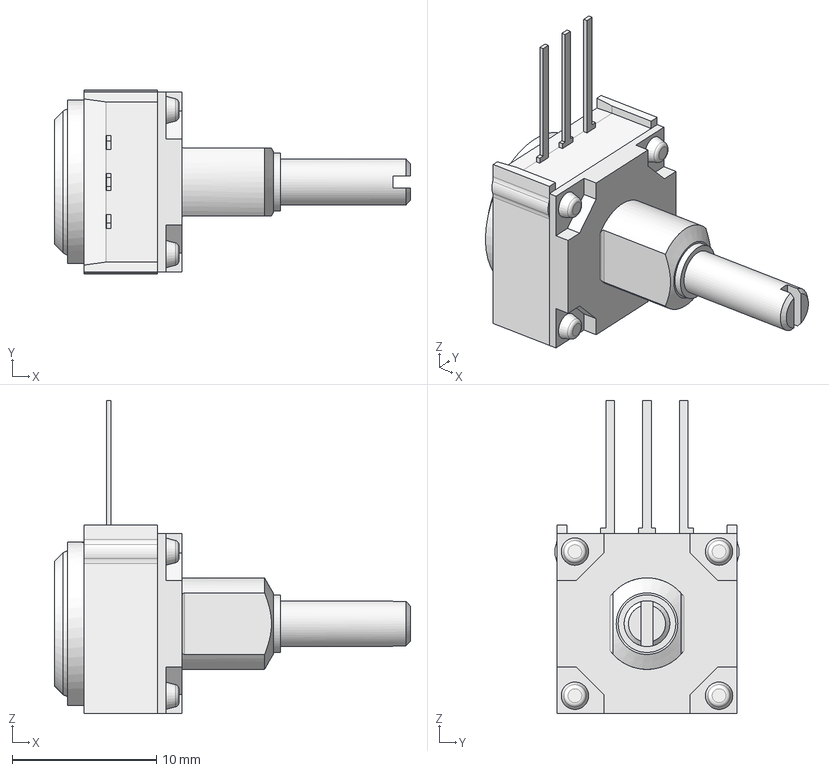
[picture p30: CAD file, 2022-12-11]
hardware/deflection_amp/3D/148-VISHAY.STP
24.7 x 12.8 x 21.8 mm

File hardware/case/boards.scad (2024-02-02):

//
// 12 x 12 inch base, all flat
//


include <3bp1.scad>
include <6sn7.scad>

sides = 1;

mm = 25.4;

// PCB standoff height
pcb_so = 0.25*mm;

// overal case dimensions
// it sort of fits in 12x12
case_wid = 12*mm;		/* X size */
case_len = 12*mm;		/* Y size */

case_hgt = 7*mm;			/* Z size */
case_thk = 1.6;

// height of CRT centerline
crt_up = 5*mm;


//
// draw a transformer
//
module transf( core_len, core_thk, winding_thk, overall_wid, height) {
     dx = core_len/5;
     dz = height/5;
     color("silver")
     translate( [0, 0, 0]) {
	  translate( [-core_len/2, -core_thk/2])
	       cube( [core_len, core_thk, height]);
	  translate( [-core_len/2, 0, 0]) cylinder( h=1, d=core_thk);
	  translate( [core_len/2, 0, 0]) cylinder( h=1, d=core_thk);
	  translate( [-dx*1.5, -winding_thk/2, dz])
	       cube( [3*dx, winding_thk, dz*3]);
     }
}



//
// draw CRT with bias board at origin
// pointing in +X
//
// PCB dimensions
crt_wid = 4.8*mm;
crt_len = 3.35*mm;

crt_tube = 9.4*mm;

crt_center_x = 47;		/* WRT corner of PCB */

module crt() {
     translate( [126, 0, -12]) {
	  rotate( [90, 0, 180]) {
	       translate( [0, 100, 0]) {
		    color("green") import("anderson_crt.stl");
		    translate( [125, -88, 3])
			 3bp1();
	       }
	  }
     }
}



cpu_wid = 4.6*mm;
cpu_len = 5.8*mm;

module cpu_stack() {
     translate( [-mm, mm+cpu_len, 0]) {
	  color("lightblue")
	       import("cpu.stl");
	  translate( [0, 0, pcb_so*2])
	       color("pink")
	       import("dac.stl");
     }
}


//
// draw deflection amp
// with corner at origin
//
amp_wid = 7*mm;
amp_len = 4*mm;

module amp() {
     translate( [-44.5, -44.5, 0])
     rotate( [0, 0, 90])
	  color("green")
	  import("deflection_amp.stl");
     // install the tubes
     translate( [49, 44, 1.6+14.5]) {
	  6sn7();
	  translate( [0, 2*mm, 0]) 6sn7();
	  translate( [0, 4*mm, 0]) 6sn7();
     }
}

//
// high voltage board stand-in
//
hv_wid = 7.0*mm;
hv_len = 4.5*mm;

module hv() {
     color("red") {
//	  cube( [hv_wid, hv_len, 1.6]);
	  rotate( [0, 0, 180])
	  translate( [-hv_wid-mm, mm, 0])
	  import("psu.stl");
     }
}


//
// toroidal transformer
//
toroid_dia = 4.5*mm;
toroid_thk = 2*mm;

module toroid() {
  color("#404040")
  cylinder( h=toroid_thk, d=toroid_dia);
}


module case() {

     cube( [case_wid, case_len, 1]);
     if( sides) {
	  % cube( [case_wid, case_thk, case_hgt]);
	  % cube( [case_thk, case_len, case_hgt]);
	  translate( [case_wid, 0, 0])
	       % cube( [case_thk, case_len, case_hgt]);
//	  translate( [0, case_len, 0])
//	       % cube( [case_wid, case_thk, case_hgt]);
     }

}


// filament transfomer
fil_a = 50;  fil_b = 21;  fil_c = 44;  fil_d = 71;  fil_h = 43;

// logic transfomer (LP-427)
log_a = 43;  log_b = 21;  log_c = 49;  log_d = 70;  log_h = 43;

// space between/around transformers
trans_spc = 0.3*mm;



module assembly() {

     case();				/* corner at origin */


// move the CRT up
     translate( [crt_wid-crt_center_x, case_len-crt_tube, crt_up]) crt();

// toroidal transformer
     translate( [toroid_dia/2+trans_spc, trans_spc+toroid_dia/2, 0.25*mm])
//     translate( [crt_wid-crt_center_x, toroid_thk+trans_spc, crt_up])  rotate( [90, 0, 0])
	  toroid();

// AMP board
//     translate( [case_wid-amp_wid, case_len-amp_len, 0.25*mm])
     translate( [case_wid, case_len-amp_len, pcb_so])
     rotate( [0, 0, 90])
	  amp();

// HV board

     // right side
     // rotate( [0, 0, 180]) translate( [-hv_wid, -case_len+cpu_len+0.5*mm, pcb_so])
     translate( [case_wid-hv_wid, case_len-hv_len-amp_len-trans_spc*2, 0.25*mm])
	  hv();
     
// logic board
     translate( [cpu_wid, case_len, pcb_so])
     rotate( [0, 0, 180])
     cpu_stack();

// transformers

     translate( [case_wid-fil_c/2-trans_spc*2, fil_d/2+trans_spc*0.6, case_thk]) {
	  rotate( [0, 0, 60]) transf( fil_a, fil_b, fil_c, fil_d, fil_h);
	  translate( [-fil_c-trans_spc, 0, 0])
	       	  rotate( [0, 0, 60]) transf( log_a, log_b, log_c, log_d, log_h);
	  translate( [2*(-log_c-trans_spc), 0, 0])
	       	  rotate( [0, 0, 60]) transf( log_a, log_b, log_c, log_d, log_h);
     }
     
//     translate( [case_wid-fil_d/2-trans_spc, fil_c/2+trans_spc, case_thk]) {
//	  transf( fil_a, fil_b, fil_c, fil_d, fil_h);
//	  translate( [-fil_d-trans_spc, 0, 0])
//	       	  transf( fil_a, fil_b, fil_c, fil_d, fil_h);
//	  translate( [2*(-fil_d-trans_spc), 0, 0])
//	       	  transf( fil_a, fil_b, fil_c, fil_d, fil_h);
//     }

}


assembly();
// hv();

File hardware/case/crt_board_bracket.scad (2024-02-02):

//
// support bracket for CRT board
//

// printed with thk=1, too thin!  Maybe 1.5 or 2?
// Also the hole_dia of 0.170 is not quite big enough for 8-32 screws
//

$fn=32;
e=0.1;

function mm(x)=x*25.4;

pcb_len = mm(3.35);
pcb_hole_off = mm(0.175);
//pcb_hole_dia = mm(0.170);
pcb_hole_dia = mm(0.180);

pcb_up = mm(0.25);

brkt_wid = mm(0.5);
brkt_z = mm(1);
//thk = 1;
thk = 2;

side_len = pcb_len-mm(0.5);

module hole_at(x,y,dia) {
     translate( [x, y, -e])
	  cylinder( h=thk+2*e, d=dia);
}

module body() {
     difference() {
	  cube( [brkt_wid, pcb_len+pcb_up, thk]);
	  hole_at( pcb_hole_off, pcb_up+pcb_hole_off, pcb_hole_dia);
	  hole_at( pcb_hole_off, pcb_up+pcb_len-pcb_hole_off, pcb_hole_dia);
     }
}

module side() {
     linear_extrude( height=thk) {
	  polygon( points = [[0,0], [0, side_len], [brkt_z, 0]]);
     }
}

module base() {
     difference() {
	  cube( [brkt_wid, brkt_z, thk]);
	  hole_at( pcb_hole_off, thk+pcb_hole_off, mm(.150));
	  hole_at( brkt_wid-pcb_hole_off, brkt_z-pcb_hole_off, mm(.15));
     }
}


body();
translate( [brkt_wid+thk-e, 0, 0]) rotate( [0, -90, 0]) side();

translate( [0, thk, 0])
rotate( [90, 0, 0])
base();

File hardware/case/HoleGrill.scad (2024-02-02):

// Grills
$fa=.5;$fs=.5;
mm=25.4;

HoleSize=4;    // inches
EdgeWidth=.3;  // inches
Webb=1 ;        //mm
Q=1;
Perf=0.17;

//Grill();
module Grill(H=HoleSize,T=Webb,W=EdgeWidth,DH=2.75,Th=Q)
{
    
    module webb()
    {
        for(x=[-H/2*mm:Perf*mm:H/2*mm]){
            //echo(x);
            translate([x,0,(Th+.2)/2])cube([T,H*mm+2,Th+.2],true);
            translate([0,x,(Th+.2)/2])cube([H*mm+2,T,Th+.2],true);
        }
    }
    intersection(){
        webb();
        cylinder(d=H*mm,Th);
    }
    difference(){
        cylinder(d=H*mm+W*mm*2,Th);
        translate([0,0,-.1])cylinder(d=H*mm,Th+.2);
        if(DH>0)for(d=[0:1:2]){
            rotate([0,0,d*360/3])translate([H*mm/2+W*mm/2,0,-.1])cylinder(d=DH,Th+0.2);
        }
    }
}

//Standoff(H=18,T=1,W=.7*mm,D=4.52*mm,C=70);
module Standoff(H,T,W,D,C)
{
    
    module slot()
    {
        hull(){
            translate([D/2-.4,0,5])rotate([0,90,0])cylinder(d=2.5,2.5);
            translate([D/2-.1,4,H-4])rotate([0,90,0])cylinder(d=2.5,2.5);
        }
    }
    
    
    difference(){
        union(){
            cylinder(d=D+T*2,H);
            cylinder(d=D+W,2.25);
        }
        translate([0,0,-.1])cylinder(d=D,H+.2);
        for(a=[0:1:C])rotate([0,0,a*360/C])slot();
        if(W>6){
            for(d=[0:1:2]){
                rotate([0,0,d*360/3])translate([D/2+W*.325,0,-.1])cylinder(d=2.75,2.5+0.2);
            }
        }
    }
    
    
    
}

// echo(40/mm);
// echo(125/mm);

//color("blue")cube([1,38,1],true);
//color("blue")cube([125,1,1],true);
//LampGrill(DrillHole=0);
module LampGrill(D=4.9-.4,EdgeWidth=.2,DrillHole=0)
{
    Q=1;

    difference(){
        union(){
            Grill(H=D,T=.65 ,W=EdgeWidth,DH=0,Th=Q);
            cylinder(d=1.8*mm,Q);
        }
        translate([0,0,-.1])cylinder(d=1.57*mm,Q+.2);
    }
}


VacuumeOutlet(print=true);
module VacuumeOutlet(print=false)
{
    D=56.06;
    Xd=17;
    
    module offset()
    {
        
        //color("blue")translate([-Xd/2,0,0])cube([D+4+Xd,1,1],true);
        difference(){
            
            union(){
                translate([-Xd/2,0,0])cylinder(d=D+Xd+5,2);
                cylinder(d=D+5,10);
            }
            translate([0,0,-.1])cylinder(d=D+.6,11);
        }

    }
    
    
    if(print){
        offset();
        translate([-Xd/2+70,40,0])Standoff(24,T=2,W=2,D=D+Xd+1,C=40);
        translate([-Xd/2,80,0])Grill(H=(D+Xd+1)/mm,T=1,W=2/mm,DH=0,Th=2);
    }else{
        offset()
        #translate([-Xd/2,0,-25])Standoff(24,T=2,W=2,D=D+Xd+1,C=40);
        translate([-Xd/2,0,-28])Grill(H=(D+Xd+1)/mm,T=1,W=2/mm,DH=0,Th=2);
    }

}

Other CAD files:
hardware/psu/3D/e_0100.2041d007.step
hardware/case/back.dxf
hardware/deflection_amp/3D/149-VISHAY.STP
hardware/psu/3D/fuse_holder-Group001.step
hardware/case/boards_stack.scad
hardware/b_250_test/3D/6T9.scad
hardware/case/3bp1.scad
hardware/case/6sn7.scad
hardware/case/base_chassis.dxf
hardware/case/base_plate.dxf
hardware/case/base_plate_12x12.dxf
hardware/case/case_fancy.scad
hardware/case/case_wide.scad
hardware/case/cpu-mech.dxf
hardware/case/crt_bottom_support.scad
hardware/case/crt_support.scad
hardware/case/deflection_amp-mech.dxf
hardware/case/front.dxf
hardware/case/fuse_bracket.scad
hardware/case/fuse_bracket.stl
hardware/case/grill.scad
hardware/case/hv_cw.scad
hardware/case/hv_cw.stl
hardware/case/hv_cw8.stl
hardware/case/hv_gen.scad
hardware/case/hv_gen.stl
hardware/case/psu-mech.dxf
hardware/case/switch_bracket.scad
hardware/case/switch_bracket.stl
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

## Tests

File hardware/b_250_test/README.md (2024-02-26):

# 6T9 Sound card

Working on a design with:

* ATTiny84a MCU
* SN76489 PSG
* 6T9 amp inspired by [this design](https://diyaudioprojects.com/Tubes/6T9-Tube-Amp-Kit/).
* Voltage doubler power supply

The output stage is based at about 30mA B+.  Hopefully the voltage doubler and 
extra winding on on the Antek can handle this OK.

Planning to use OT8SE+HF+5K transformer I have lying around from MPS.
It's rated at 45mA DC.

Layout ~ done.  Many parts have DigiKey "TR" option, need to fix this.

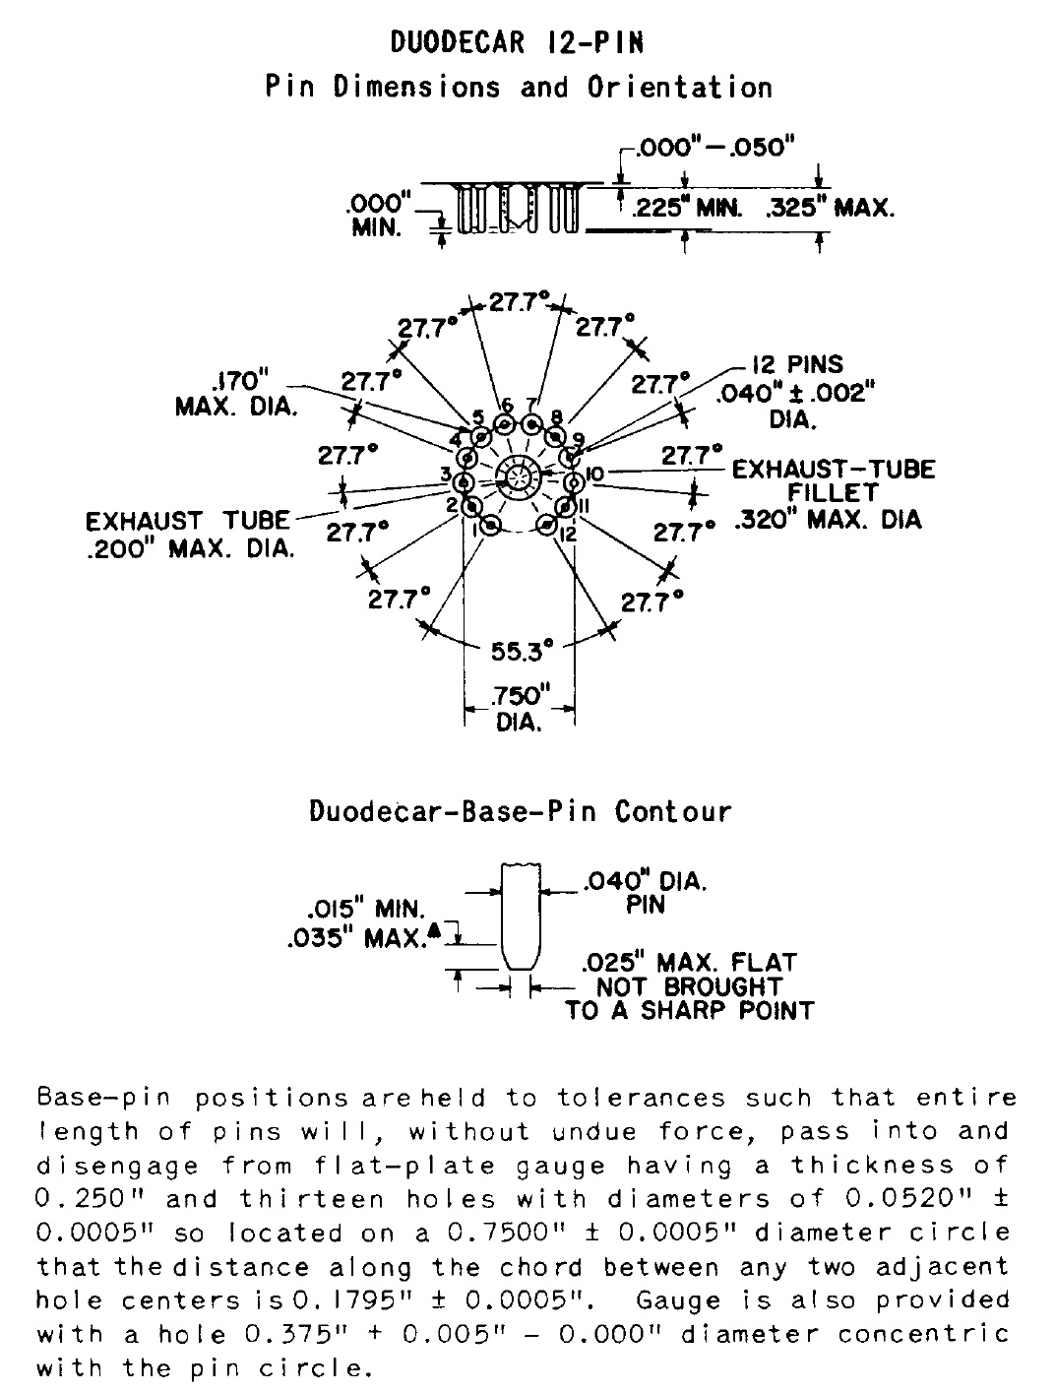
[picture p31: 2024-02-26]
hardware/b_250_test/3D/duodecar.jpg

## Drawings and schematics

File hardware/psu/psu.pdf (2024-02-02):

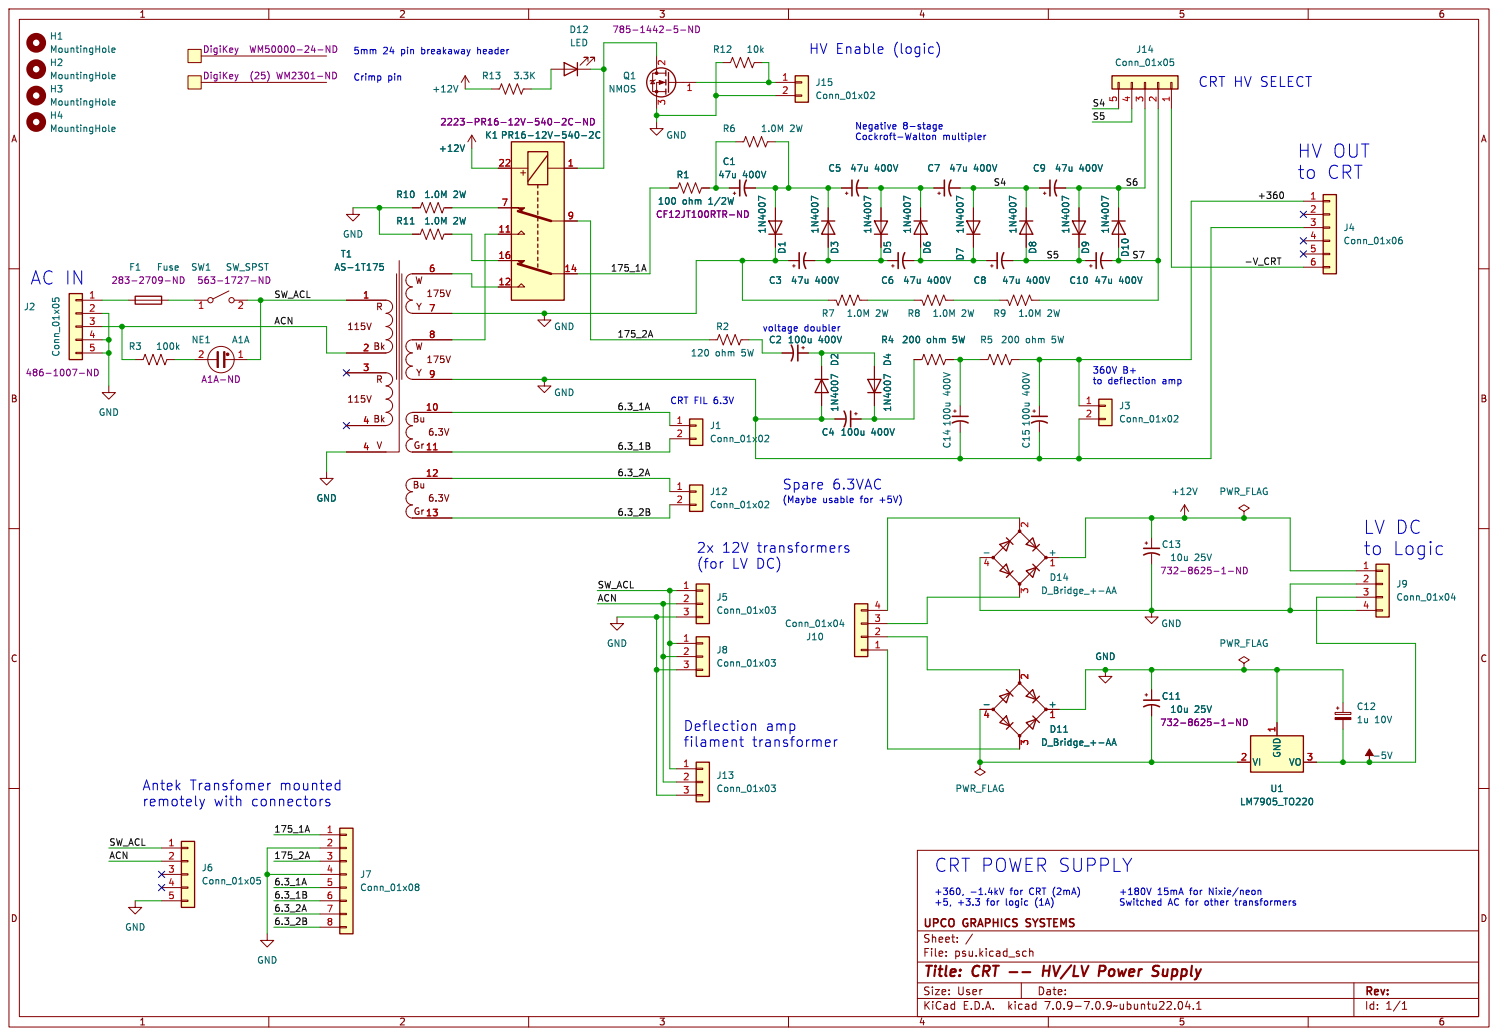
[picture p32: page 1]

H2 MountingHole H3 MountingHole H1 MountingHole H4 MountingHole

File: psu.kicad_sch Sheet: / UPCO GRAPHICS SYSTEMS D9 1N4007

+180V 15mA for Nixie/neon Switched AC for other transformers

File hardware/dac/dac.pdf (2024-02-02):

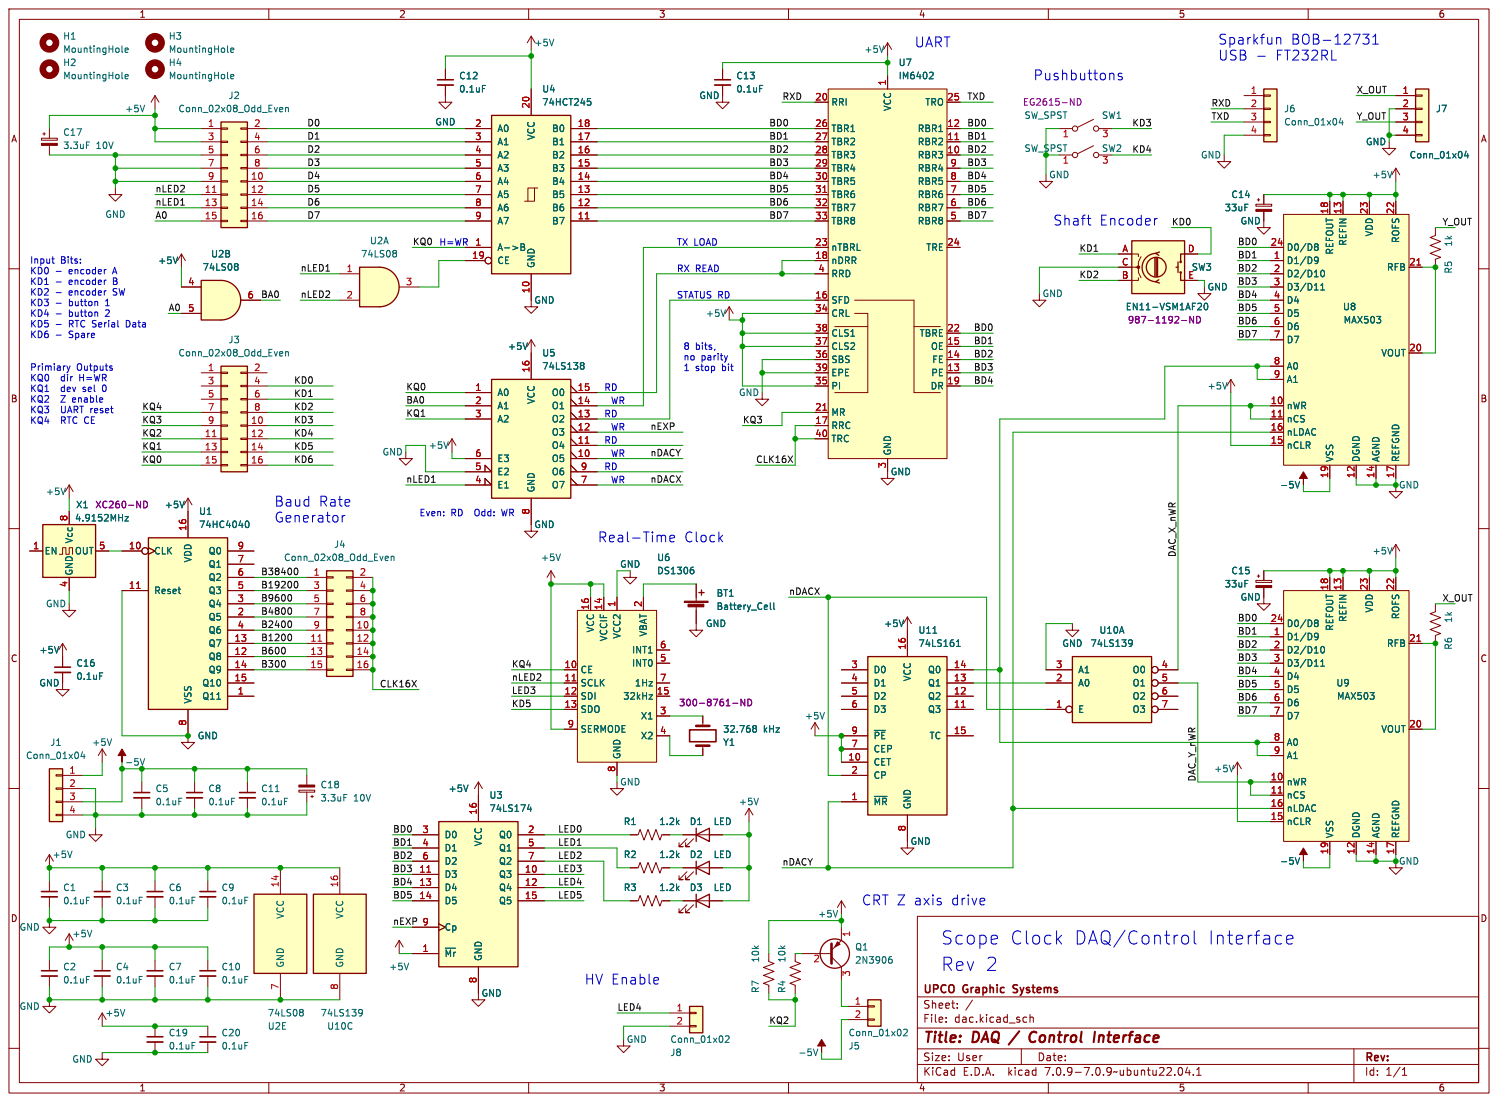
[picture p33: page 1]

3 TBR5 30 TBR6 31 TBR7 32 TBR8 33 CRL 34 PI 35 SBS 36 CLS2 37 CLS1 38 EPE 39 RRD 4 TRC 40 RBR8 5 RBR7 6 RBR6 7 RBR5 8 RBR4 9 U7

1 RBR3 10 RBR2 11 RBR1 12 PE 13 FE 14 OE 15 SFD 16 RRC 17

3 TBR5 30 TBR6 31 TBR7 32 TBR8 33 CRL 34 PI 35 SBS 36 CLS2 37 CLS1 38 EPE 39 RRD 4 TRC 40 RBR8 5 RBR7 6 RBR6 7 RBR5 8 RBR4 9 GND

1 CE 10 SCLK 11 SDI 12 SDO 13 VCCIF 14

Id: 1/1 Title: DAQ / Control Interface

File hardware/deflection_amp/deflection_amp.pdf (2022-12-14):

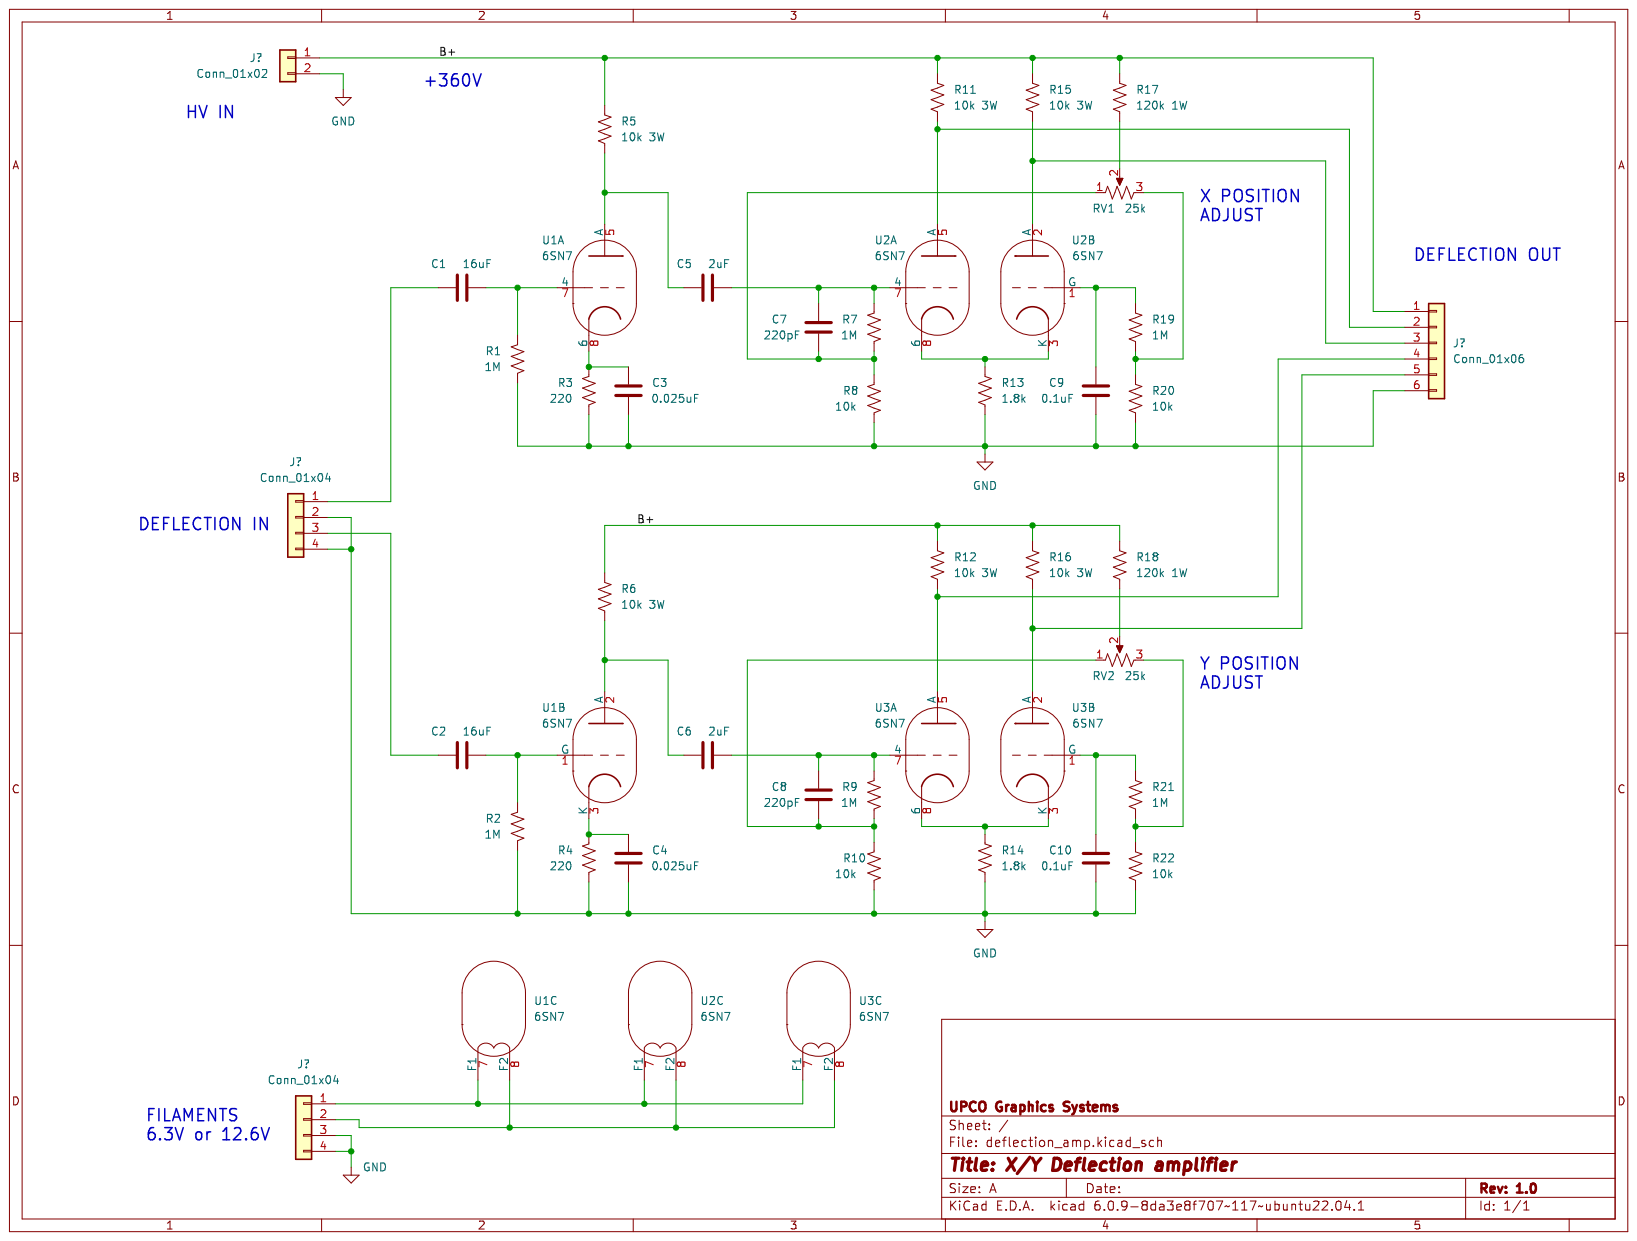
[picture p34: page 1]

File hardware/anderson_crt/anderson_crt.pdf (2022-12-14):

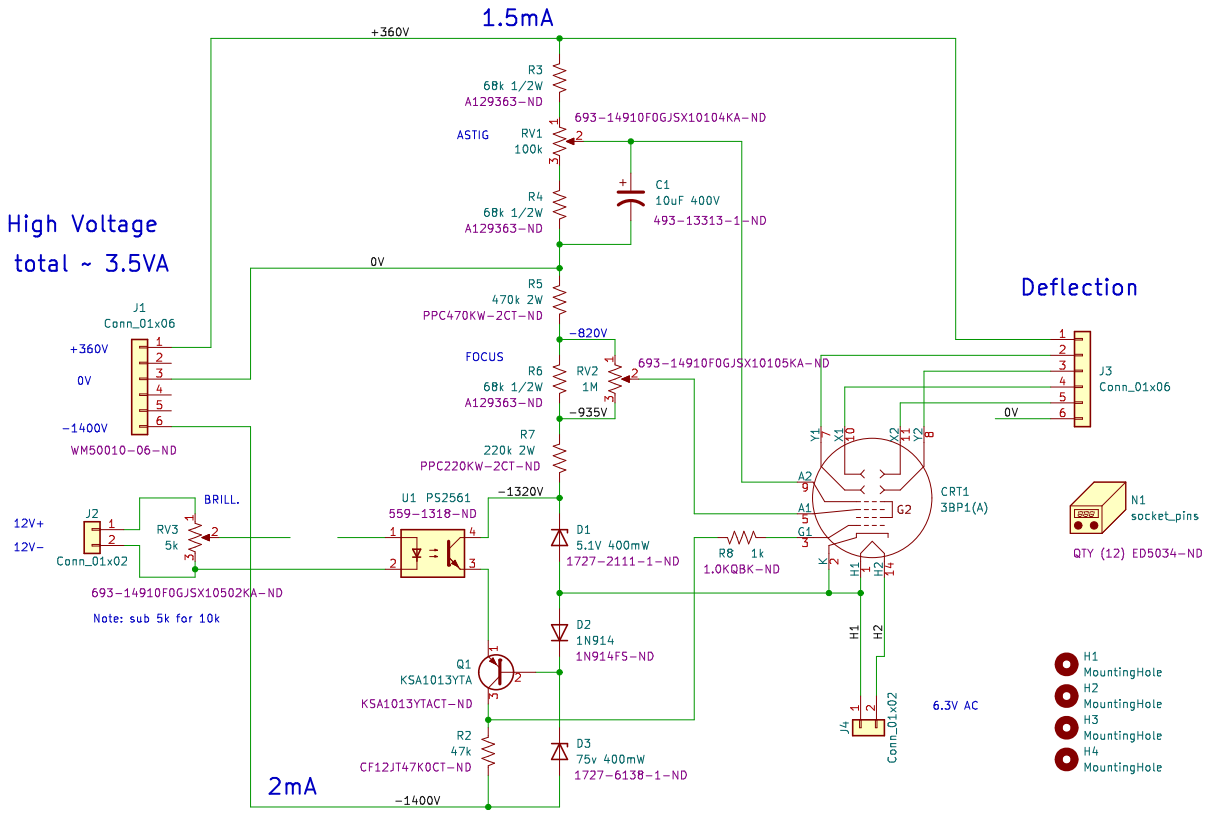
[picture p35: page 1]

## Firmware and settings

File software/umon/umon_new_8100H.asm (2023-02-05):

;;;
;;; simple Z80 monitor
;;;
;;; d <addr> <count>           dump memory
;;; e <addr> <dd> <dd>...      edit up to 16 bytes in memory
;;; o <port> <val>             output <val> to <port>
;;; z <val>		       set port zero value bits 0-6
;;; i <port>                   input from <port> and display
;;; g <addr>                   goto addr
;;; b <addr>                   set breakpoint (currently 3-byte call)
;;; a <val1> <val2>            hex Arithmetic
;;; c                          continue from breakpoint
;;; c <addr>                   continue, set new breakpoint
;;; m <start> <end> <size>     memory region compare
;;; p <start> <end> <size>     memory region copy
;;; r                          display stored regs
;;; r <reg> <val>              edit stored regs
;;; l			       binary load
;;; /			       repeat last command
;;; 
;;; calculator hardware
;;; f <addr>                   dump HP registers from <addr> (A)
;;; k                          scan keyboard
;;; 7 <addr>		       update 7-segment display from <addr>
;;; V <addr>                   update VFD display from <addr>
;;;
;;; scope hardware
;;; s <Xvalue> <Yvalue>	       set scope X, Y dac values
;;; 
;;; 
;;; New version, mostly new comments and modularity
;;; intended to be more portable, and include all features
;;; Fixes:  	GOTO now pushes breakpoint, sets regs
;;; 		register edit/display
;;;		bit-bang serial preserves register 0 bits 0-6

;;; ---------- compile options ----------
calc_hw equ	0		; support for calculator hardware
readline equ	1		; GNU-readline like command recall
debug	equ	0		; some debug support
scope	equ	1		; support for scope expansion board
	
; 	org	08100H
 	org	8100H	

stak:	equ	$		;stack grows down from start

;;; jump table for useful entry points
jump_table:	
	jmp	main		;0  cold start
	jmp	save_state	;1  save state (breakpoint)
	jmp	getc		;2  read serial input to A
	jmp	putc		;3  output serial from A
	jmp	crlf		;4  output CR/LF
	jmp	puts		;5  output string from HL
	jmp	phex2		;6  output hex byte from A
	jmp	phex4		;7  output hex word from HL
if scope
	;; scope expansion support
	jmp	uart_rst	;8  reset UART
	jmp	uart_rx		;9  Receive UART to A (blocking)
	jmp	uart_tx		;0a send UART from A (blocking)
	jmp	write_led	;0b write LED/control latch
	jmp	dac_x		;0c write 12 bits to X DAC
	jmp	dac_y		;0d write 12 bits to Y DAC
endif	
	jmp	0000h		;8/0e  marks end of table for error check

;;; ---- data area (must be in RAM)  ----

jumptbl: dw	jump_table	;default jump table for 'f' command

;;; save CPU state coming from extrnal prog
savein:	db	0,0,0		;instruction overwritten by breakpoint
savead:	dw	0		;address of breakpoint
savesp:	dw	0		;caller's stack pointer

;;; saved registers
saviy:	dw	0
savix:	dw	0

savhlp:	dw	0
savdep:	dw	0
savbcp:	dw	0
savafp:	dw	0
	
savhl:	dw	0
savde:	dw	0
savbc:	dw	0
savaf:	dw	0
	
savetop: equ	$

bufsiz:	equ	60		;command buffer size

;;; readline-style recall buffers
if readline
nrecall: equ	3		;number of recall buffers
	
recbuf:	rept	nrecall
	rept	bufsiz
	db	0
	endm
	endm

recptr:	dw	0
	
endif	
	
lastc:	db	0		;last command byte

buff:	rept	bufsiz
	db	0
	endm

bend:	equ	$		;mark the end

maxarg:	equ	18		;maximum number of arguments
argc:	db	0
	
argv:	rept	maxarg*2
	dw	0
	endm
	
iargv:	rept	maxarg*2
	dw	0
	endm

	INCLUDE "s19200.asm"	
	INCLUDE "console.asm"	; gets, puts, space, crlf etc
	INCLUDE "hex.asm"	; hex I/O
	INCLUDE "strings.asm"	; strtok()
;	INCLUDE "c-link.asm"
if calc_hw	
	INCLUDE "vfd.asm"
	INCLUDE "diskey.asm"
endif	
if scope
	INCLUDE "scope.asm"
endif	

banner:	db	"UMON v0.9b ORG ",0
error:	db	"ERROR",0
	
usage:  db      "h                     print this help", 13, 10
        db      "d <addr> <count", 13, 10
        db      "d <addr> <count>      dump memory", 13, 10
        db      "e <addr> <dd> <dd>... edit up to 16 bytes in memory", 13, 10
        db      "o <addr> <val>        output <val> to port <addr>", 13, 10
        db      "z <val>               set port zero value bits 0-6", 13, 10
        db      "i <addr>              input from <addr> and display", 13, 10
        db      "g <addr>              goto addr", 13, 10
        db      "b <addr>              set breakpoint (currently 3-byte call)", 13, 10
        db      "a <val1> <val2>       hex Arithmetic", 13, 10
        db      "g <addr>              dump HP registers from <addr> (A)", 13, 10
	db	"m <ad1> <ad2> <n>     memory compare", 13, 10
	db	"p <ad1> <ad2> <n>     memory copy", 13, 10
	db	"r                     display stored regs", 13, 10
	db      "r <reg> <val>         edit stored regs", 13, 10
        db      "c                     continue from breakpoint", 13, 10
        db      "l                     binary load", 13, 10
	db	"f <func>              call function from jump table", 13, 10
	db      "j [<addr>]            set/display jump table start addr", 13, 10
        db      "^P                    repeat last command", 13, 10
if calc_hw	
        db      "k                     scan keyboard", 13, 10
        db      "7 <addr>              update LED display from <addr>", 13, 10
        db      "V <addr>              update VFD display (0=blank)", 13, 10
endif	
if scope
	db	"s <DACX> <DACY>       set scope DAC values", 13, 10
endif	
	db	0

;;; -------------------- MAIN entry point --------------------
	
	;; set stack, display banner, print code range
main:	ld	sp,stak
	ld	hl,banner
	call	puts
	ld	hl,stak
	call	phex4
	call	space
	ld	hl,umontop
	call	phex4
	call	crlf
	
loop:	ld	a,'>'		;prompt
	call	putc

	;; get command
	ld	hl,buff
	ld	bc,bend-buff	; maximum size
	call	gets

if debug
	;; dump buffer
	ld	hl,buff
	ld	b,bend-buff
	call	hdump
endif	
	;; check for ^P
	ld	a,(buff)
	cp	a,10h
	jr	nz,not_rept
	;; we got a ^P
if readline
	;; recall buffer
	ld	hl,recbuf
	ld	de,buff
	ld	bc,bufsiz
	ldir
	;; pull the recall stack down
	ld	hl,recbuf+bufsiz
	ld	de,recbuf
	ld	bc,bufsiz*(nrecall-1)
	ldir
	;; print the current buffer
	ld	hl,buff
	call	puts
not_rept:	
	;; not a ^P, store in recall stack
	;; first move everything in stack up
	ld	hl,recbuf
	ld	de,recbuf+bufsiz
	ld	bc,bufsiz*(nrecall-1)
	ldir

	;; now copy buffer to stack
	ld	hl,buff
	ld	de,recbuf
	ld	bc,bufsiz
	ldir
else
	;; restore last command byte
	ld	a,(lastc)
	ld	(buff),a
not_rept:
endif	
	;; parse string into tokens at argc / argv
	ld	hl,buff
	ld	de,argv
	ld	b,maxarg
	call	strtok	
	ld	a,c
	ld	(argc),a

	;; convert tokens to integers
	ld	hl,argv
	ld	de,iargv
	ld	b,a
	call	cvint

	ld	hl,buff		;parse command character
	ld	a,(hl)
	ld	(lastc),a	;save for possible repeat

	cp	a,'D'		;dump memory
	jz	dump

	cp	a,'H'
	jz	help

	cp	a,'A'
	jz	arith

	cp	a,'E'
	jz	edit

	cp	a,'B'
	jz	brkpt

	cp	a,'C'
	jz	continu

	cp	a,'G'
	jz	goto

	cp	a,'L'
	jz	binary
	
	cp	a,'O'
	jz	output

	cp	a,'R'
	jz	edit_regs

	cp	a,'I'
	jz	input

	cp	a,'Z'
	jz	zero

	cp	a,'F'
	jz	call_func

	cp	a,'J'
	jz	set_jumptbl
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

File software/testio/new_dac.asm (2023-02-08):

;;;
;;; test_dac.asm - ramp the DACs
;;;
;;; also prototype library for expansion board

;;; bits in keyboard latch (port 00)
KBQ_WR:		equ	1	;select write mode
KBQ_SEL:	equ	2	;device select
KBQ_Z:		equ	4	;CRT Z enable
KBQ_UART_RST:	equ	8	;UART reset
KBQ_RTC_CE:	equ	10h	;RTC chip enable
KBQ_SER_DAT:	equ	80h	;bit-bang serial out

umon:	equ	8100h		;re-enter umon

dlist:	equ	0a200h

serial_port:	equ	80H	;inputport
led_port:	equ	0	;port 0 for LED/keyboard output
	
data_bit:	equ	80H	;input data mask

	org	0a000h		;above UMON
	
	jp	dpy_list	;0
	jp	echo		;1
	jp	uart_rx		;2
	jp	uart_tx		;3
	jp	uart_st		;4
	jp	write_led	;5
	jp	ldac		;6
	jp	wdac		;7
	jp	uart_rst	;8
	jp	dpy_list	;9
	jp	0000h		;end of table

dval:	dw	8

;;; write display list from memory
;;; display list format:
;;;     <count>
;;;       <xlow> <xhigh> <ylow> <yhigh>
;;;       <xlow> <xhigh> <ylow> <yhigh>
;;;           ...
;;;     <count>
;;;       <xlow> <xhigh> <ylow> <yhigh>
;;;       <xlow> <xhigh> <ylow> <yhigh>
;;;           ...
;;; count must be a multiple of 4; FF marks end of list
;;; so 4 = 1 point,  8 = 2 points, 0 = 64 points

dpy_list:
;	call	uart_rst
dpy_loop:	
;	call	uart_st		;test UART
;	and	10h
	;; check bit-bang UART
	in	a,(serial_port)
	and	data_bit
	jp	z,umon
	
;	jp	nz,umon

	ld	hl,dlist
	
	ld	a,data_bit+3
	out	(led_port),a	;set control address to '11'
	ld	c,41h		;data port

dpy1:	ld	b,(hl)		;get count
	inc	hl		;point past count
	inc	b
	jr	z,dpy_loop
	dec	b		;restore count


dpy2:
	;; set the Z axis
	outi			;send LSB of X
	;; check for move/draw in LSB of X
	bit	7,(hl)		;first byte bit 7 set for draw
	ld	a,data_bit+3	;default bit 2=0, beam on for draw
	jr	nz,dodraw
	;; move, turn off the Z
	ld	a,data_bit+7
dodraw:	
	out	(led_port),a

	outi
	outi
	outi

	;; delay before asserting LDAC for the Z axis to settle
	push	af
	call	delay
	pop	af

	out	(40h),a		;activate nLDAC
	
	;; turn off the beam
	ld	a,data_bit+7
	out	(led_port),a
	push	af
	call	delay
	pop	af

	jr	nz,dpy2
	
	jr	dpy1

;;; test writing to DAC over and over until UART
test_dac:
	call	uart_rst
dac_loop:	
	call	uart_st		;test UART
	and	10h
	jp	nz,umon

	;; first do reset
	call	ldac
	;; write to DACs (12 bits HL, DE)
	call	wdac
	inc	hl
	inc	de
	jr	dac_loop

	;; slow test for scope debug

	call	delay

	;; write 4 times to DAC with delays
	ld	a,data_bit+3
	out	(led_port),a

	ld	a,55h
	
	out	(41h),a
	call	delay

	out	(41h),a
	call	delay

	out	(41h),a
	call	delay

	out	(41h),a
	call	delay

	ld	a,d
	call	write_led
	inc	d

	jr	dac_loop
	


;;; delay
delay:	push	hl
	ld	hl,(dval)
dily1:	dec	hl
	ld	a,h
	or	l
	jr	nz,dily1
	pop	hl
	ret

;;; echo the UART
echo:	call	uart_rst

echo1:	call	uart_st
	and	10h
	jr	z,echo1
	
	call	uart_rx
	cp	a,'$'
	jp	z,umon
	call	uart_tx
	jr	echo1
	
uart_rst:
	ld	a,KBQ_UART_RST
	out	(0),a		;assert reset
	xor	a
	out	(0),a		;clear reset
	ret


;;; select device and perform I/O operations

;;; read from UART data register to A
uart_rx:
	ld	a,data_bit	;low bits 00
	out	(led_port),a
	in	a,(40h)
	ret

;;; write to UART data register from A
;;;   uses: E
uart_tx:
	ld	e,a
	ld	a,data_bit+1	;low bits 01
	out	(led_port),a
	ld	a,e
	out	(40h),a		;write data
	ret

;;; read UART status to A
uart_st:
	ld	a,data_bit	;low bits 00
	out	(led_port),a
	in	a,(41h)
	ret

;;; write LEDs from A
;;;   uses: E
write_led:
	ld	e,a
	ld	a,data_bit+1	;low bits 11
	out	(led_port),a
	ld	a,e
	out	(41h),a
	ret

;;; reset, LDAC
ldac:	ld	a,data_bit+3
	out	(0),a
	ld	a,h		;test data FIXME
	out	(40h),a		;data unimportant
	ret

;;; write DAC X, Y from HL DE
wdac:	ld	a,data_bit+3
	out	(led_port),a
	ld	c,41h
	out	(c),l
	out	(c),h
	out	(c),e
	out	(c),d
	jr	ldac

	org	dlist

	.include "list.asm"

	.end
	

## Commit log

2022-12-09 Schematic mostly done
    [power.kicad_sch, scope-clock.kicad_pcb, scope-clock.kicad_sch]
2022-12-11 PCB done?
    [026482065.stp, 148-VISHAY.STP, 149-VISHAY.STP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]
2022-12-14 Draft deflection amp schematic
    [3bp1.scad, anderson_crt.kicad_pcb, anderson_crt.ods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]
2022-12-14 Anderson PCB as built
    [anderson_crt-B_Cu.gbr, anderson_crt-B_Mask.gbr, anderson_crt-B_Paste.gbr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]
2022-12-14 deflection schematic
2022-12-14 Draft deflection amp pcb done
    [026482065.stp, 148-VISHAY.STP, 149-VISHAY.STP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]
2022-12-15 starting on 3D assembly, routed the deflection PCB
    [3bp1.scad, 6sn7.scad, anderson_crt.kicad_pcb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]
2022-12-16 3d cap holder
    [hv_gen.scad, hv_gen.stl]
2022-12-17 Power supply schematic mostly done
    [boards.scad, psu.kicad_pcb, psu.kicad_sch]
2022-12-19 ps board
    [boards.scad, psu.kicad_pcb, psu.kicad_sch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]
2022-12-22 add 3d models, work on ps
    [boards.scad, e_0100.2041d007.step, fuse_holder-Group001.step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]
2022-12-28 update 3D stuff
    [fuse_bracket.scad, fuse_bracket.stl, switch_bracket.scad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]
2022-12-31 Starting DAC/control board
    [dac.kicad_pcb, dac.kicad_sch]
2023-01-02 DAC layout almost done
    [dac.kicad_pcb, dac.kicad_sch]
2023-01-02 PCB Rev 1 ready to fab?
    [dac.kicad_pcb, dac.kicad_sch]
2023-01-04 Orders placed for PCBs and parts
    [cpu-Edge_Cuts.dxf, cpu-F_Mask.dxf, cpu_dac_bom_order.ods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]
2023-01-07 rework power supply, still needs footprint/placement work
    [psu.kicad_pcb, psu.kicad_sch]
2023-01-08 Add some stuff to PSU
    [psu.kicad_pcb, psu.kicad_sch]
2023-01-09 working on chassis layout
    [boards.scad, dac.kicad_pcb, psu.kicad_pcb]
2023-01-09 3D model
    [boards.scad]
2023-02-07 Add CRT voltage select jumper
    [psu.kicad_pcb, psu.kicad_sch]
2023-02-07 Mess with 3D model, clean schematic ERC errors
    [boards_stack.scad, psu.kicad_sch]
2023-02-10 working on PSU
    [psu.kicad_pcb, psu.kicad_sch]
2023-02-10 PSU layout done?
    [psu.kicad_pcb, psu.kicad_sch, relay-Group003.step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]
2023-02-12 PSU Rev A
    [psu-B_Cu.gbr, psu-B_Mask.gbr, psu-B_Silkscreen.gbr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]
2023-02-13 working on Rev 2 DAC
    [dac-B_Cu.gbr, dac-B_Mask.gbr, dac-B_Silkscreen.gbr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]
2023-12-28 software tweaks, working on case
    [800SP9B6M6RE.step, EN11-VSM.STP, boards.scad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]
2023-12-30 gerbers as built (DAC), 3D case wide version
    [3bp1.scad, HoleGrill.scad, base_chassis.dxf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]
2023-12-30 slight case update
    [case_wide.scad]
2023-12-30 schematic notes
    [dac.kicad_sch]
2024-01-22 readme, test sw
    [base_chassis.dxf, case_wide.scad]
2024-01-23 start support
    [crt_support.scad]
2024-01-23 CRT brackets
    [crt_board_bracket.scad, crt_support.scad]
2024-01-24 two-part CRT support/clamp
    [crt_bottom_support.scad]
2024-02-02 CRT bracket
    [crt_bottom_support.scad]
2024-02-02 front panel
    [case_wide.scad, dac.kicad_pcb, deflection_amp.kicad_pcb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]
2024-02-05 case parts, start sound board design
    [back.dxf, left.dxf, right.dxf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]
2024-02-05 fix front
    [front2.dxf]
2024-02-05 working on placement
    [sound.kicad_pcb, sound.kicad_sch]
2024-02-05 work on placement, HV clearance
    [sound.kicad_pcb, sound.kicad_sch]
2024-02-06 transformer cover
    [trans_cover.scad]
2024-02-07 250V B+ test design start
    [b_250_test.kicad_pcb, b_250_test.kicad_sch]
2024-02-07 working on 6T9 version of sound
    [b_250_test.kicad_pcb, b_250_test.kicad_sch]
2024-02-07 working on 6T9 design
    [b_250_test.kicad_pcb, b_250_test.kicad_sch]
2024-02-26 first pass place & route
    [b_250_test.kicad_pcb, b_250_test.kicad_sch]
2024-02-26 parts parts parts
    [b_250_test.kicad_sch]
2024-02-26 3D tube model
    [6T9.scad, 6T9.step, b_250_test.kicad_pcb]
2024-02-26 add 12-pin socket dwg
2024-02-28 silkscreen and minor tweaks
    [b_250_test.kicad_pcb, b_250_test.kicad_sch]
